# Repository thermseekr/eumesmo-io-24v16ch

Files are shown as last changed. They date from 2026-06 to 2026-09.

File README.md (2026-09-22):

# eumesmo-io-24v16ch
ESP32 based board with 16x optoisolated 24 VDC active high inputs, and 16x open collector 24 VDC outputs.

The outputs are based on the MMBT2222A SMD transistor and are rated for a maximum of 500mA, although it is recommended to limit the current to 350 mA for continous operation. If driving inductive loads like relays, a freewheeling diode or a snubber circuit should be used to limit the switching transients and protect the transistors.

Also included is a 1-Wire interface for external sensors. This interface can be switched to connect either to GPIO16 for use with a bitbang driver like the one available in Tasmota, or to a DS2482S-100 1-Wire master for building more complex networks. Selection is made via SW2, according to the description printed on the PCB. **Attention:** only one dip-switch can be on at any given time.

The board is compatible with the SP7 DIN rail system from [Metaltex](https://www.metaltex.com.br/).

## Hardware Specifications

| Feature | Specification |
| :--- | :--- |
| **Microcontroller** | ESP32-WROOM-32UE-N16 (16MB flash) |
| **Inputs** | 16x 24VDC (optoisolated, active high) |
| **Outputs** | 16x 24VDC (open collector, 350mA cont. / 500mA peak) |
| **Peripherals** | 1-Wire Interface, via GPIO or 1-Wire master |
| **Form Factor** | Metaltex DIN Rail holder Compatible |

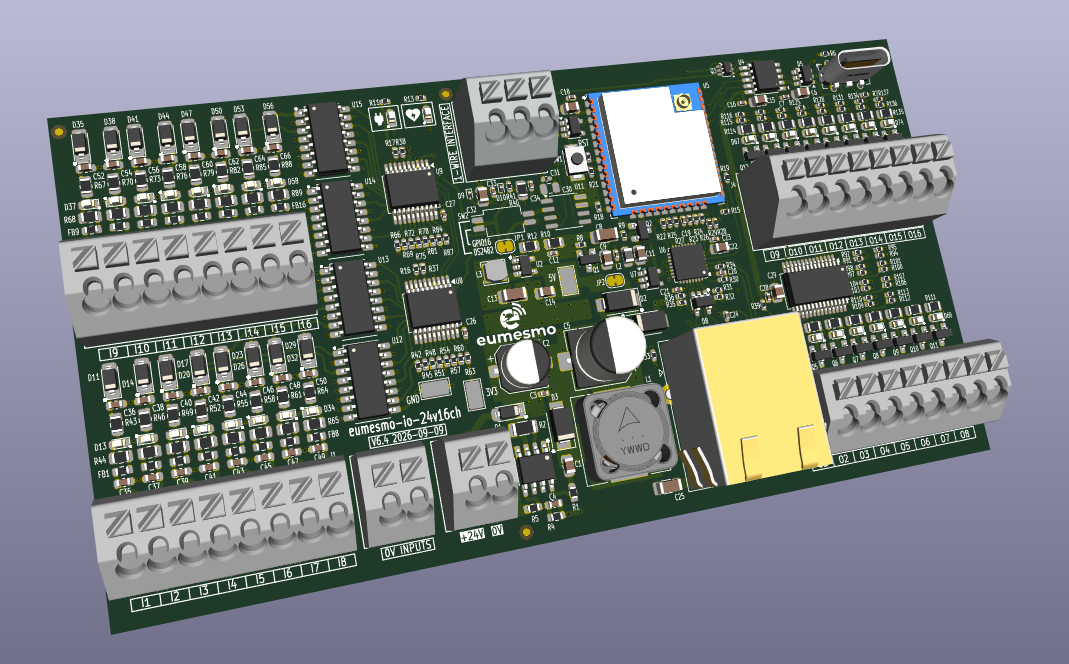
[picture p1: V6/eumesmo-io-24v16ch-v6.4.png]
eumesmo-io-24v16ch V6.4


## VERSION HISTORY

V6.4 - 2026/09/22 - Ethernet connector and terminal blocks moved inwards the PCB to eliminate interference with the PCB holder and make space for the pin descriptions. Tracks between connector and LAN8710A rerouted for improved EMC. LEDs switched from white to orange. Replaced TPS3823-33 for a TPS3820-33 as the LAN8710A reset monitor: the 200ms delay was too much and by the time the chip came up, the ESP32 had already finished booting and had not found it.

V6.3 - 2026/07/02 - Added CPU health LED.

V6.2 - 2026/06/13 - Repository renamed from ESP-24V-16CH to eumesmo-io-24v16ch to align the design with the **eumesmo** line of building automation products.

V6.1 - 2026/06/09 - Added voltage monitors for the reset pins on the ESP32 and LAN8710A, replacing the RC circuits. The idea is to get more reliability on the power up sequence with a more controlled reset scheme and a sharper edge on the reset signal. For the ESP32 a TPS3820-33 was selected, which has a reset delay of 25ms. The LAN8710A received a TPS3823-33 with a 200ms delay. The sequence is: ESP32 gets power and goes out of reset 25ms after power good is detected at the 3V3 rail. After boot GPIO12 will go high enabling the 3V3LAN power rail and feeding power to both LAN8710A and TPS3823-33. Then, 200ms after power good is detected on the 3V3LAN rail, the LAN8710A will go out of reset and the power sequence is completed.

V6.0 - 2026/06/06 - The ESP32 was repositioned to allow for better routing to/from the PHY. Test points and a shunt resistor on the 5V rail were added to be used during tests. Will be remove in later versions. A separate GND plane and connector for optocouplers inputs was included. New ethernet connector, with tab up for easier integration with DIN holders from Metaltex. Connectors were replaced for 3.5mm pitch versions for easier wiring installation in the field. The board had to grow 10mm to accomodate these. SMD capacitor sizes were revised for better performance. Transistor base current for the ouputs was increased from 2,3mA to 5,5mA to ensure better saturation. Now, higher loads can be driven without the risk of putting the transistor in the active region. The MCP23017 expander for the inputs was replaced by 2x MCP23008 to avoid the infamous MCP23017 input bug. Rpacks were replaced for individual resistors for more flexible layout. Talking about layout, it was fully revised with better impedance matching for LAN8710 Tx/Rx signal traces. At last, the loads for 3V3A and 3V3LAN rails were revised.

V5.2 - 2026/02/10 - Pins GPA7 and GPB7 of the input MCP23017 were disabled as recommended by Microchip. Inputs 1 and 2 were assigned to GPIO34 and GPIO35 on the ESP32. The mentioned pins were pulled down to 0V and disabled on the mcp23x.dat template. Templates and GPIO assignment information on the schematics were updated.

V5.1 - Corrected footprint of R7 and repositioned the RESET switch as noted by [@yvkoch](https://github.com/yvkoch). Thanks Yrjö! Improved the 1-Wire bus interface aiming for cable runs up to 50m, still to be tested. Also included the option to connect a GPIO to the 1-Wire bus. ATENTION, SW2 can only have one switch ON at any given time, to connect either the DS2482 or GPIO16 to the 1-Wire bus.

V5.0 - Removed the onboard temperature sensor, too sensitive to be on a PCB and also measure the ambient temperature inside the cabinet. Even with cuts around the sensor, it was better at measuring each transistor's influence on the PCB's temperature than the temperature of the environment. Replaced the analog NTC inputs for a 1-Wire i2c interface. Mixing analog and digital circuits on a PCB requires more testing and developing time than I have available. So, fully digital we go. Decreased the brightness of the LEDs, maybe this time I'll get them right :) Repositioned components and rerouted the whole board following the valuable insights taken from [Phil's Lab](https://github.com/pms67) latest videos about Kicad. Thank you very much, Phil.

V4.1 - Redesigned NTC inputs for using differential mode for better immunity against noise. Also the low pass filters were redesigned, the original ones were pretty much useless for any cable larger that 2 meters.

V4.0 - Redesigned digital inputs for better tolerance to long cable runs in noisy environment. Removed pads for NTC inputs 3 and 4, tied them to GND.

V3.2 - Added 4 NTC inputs using an ADS1115 A/D converter with i2c. Reduced current on the LEDs, brightness was too high. Added series resistor and rerouted clock track for better impedance and ring control. Rerouted TX/RX and SCL/SDA tracks for improved signal quality. Layers reordered so the ground plane is directly below the top layer. Returned ESP32 to 16MB version.

V3.1 - Added AHT20 onboard temperature and humidity sensor for cabinet environment monitoring. Replaced ESP32 16MB for 4MB because no stock at JLCPCB.

V3 - Power LED moved to 5V bus. Individual resistors replaced for rpacks where applicable. Moved from 2 to 4 layers, board reduced 30mm in lenght. USB connector repositioned and replaced for horizontal version.

V2 - All GPIOs moved to MCP23017 expanders. MCP interrupt pins connected to GPIOs on the ESP32. USB connector changed for USB type C.

V1 - Initial version, not released. The first 8 inputs used native ESP32 GPIOs, other inputs and all outputs were wired through MCP GPIO expanders.

## LICENSE

This project is licensed under the [Creative Commons BY-NC 4.0 License](https://creativecommons.org/licenses/by-nc/4.0/).
Commercial use is not permitted without prior written consent. See the [LICENSE.txt](LICENSE.txt) file for details.

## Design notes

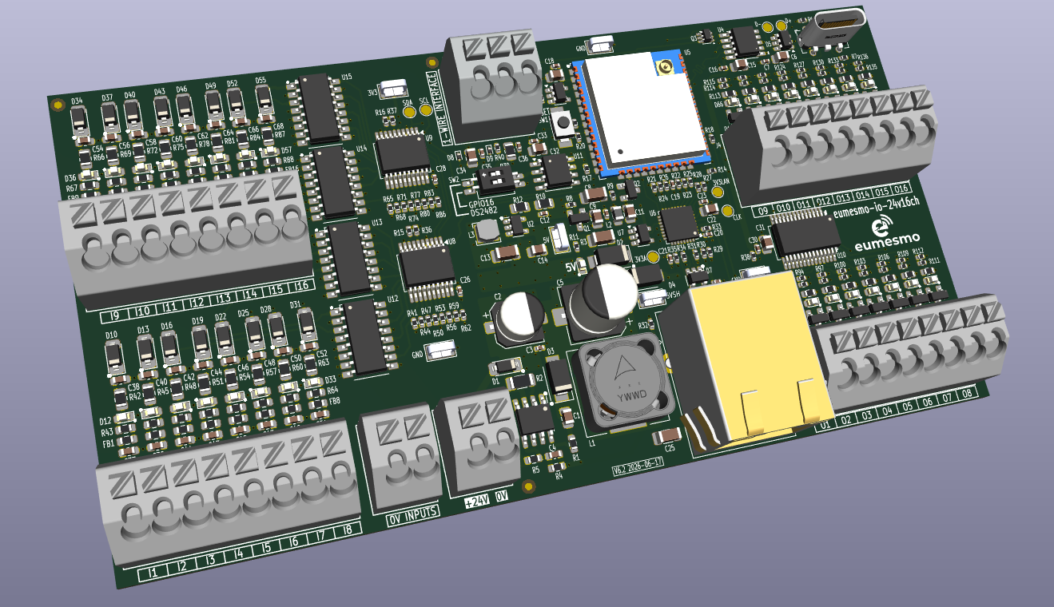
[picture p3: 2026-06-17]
V6/eumesmo-io-24v16ch-v6.2.png

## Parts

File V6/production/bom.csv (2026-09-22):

Designator | Footprint | Quantity | Value | LCSC Part #
C1 | 0805 | 1 | 100nF/100V | C28233
C10, C16, C18, C19, C20, C21, C24, C26, C27, C28, C3, C33, C7 | 0402 | 13 | 100nF/50V | C307331
C11, C14, C15, C17, C29, C32, C9 | 0805 | 7 | 10uF/25V | C15850
C12 | 0402 | 1 | 22pF/50V | C1555
C13, C8 | 1206 | 2 | 22uF/10V | C5672
C2 | CP_Elec_6.3x5.4 | 1 | 47uF/35V | C129415
C22, C6 | 0805 | 2 | 1uF/50V | C28323
C23, C34 | 0402 | 2 | 470pF/50V | C1537
C25 | 1206 | 1 | 1nF/2kV | C9196
C35, C37, C39, C41, C43, C45, C47, C49, C51, C53, C55, C57, C59, C61, C63, C65 | 0603 | 16 | 1nF/50V | C1588
C36, C38, C40, C42, C44, C46, C48, C50, C52, C54, C56, C58, C60, C62, C64, C66 | 0603 | 16 | 33nF/50V | C21117
C4 | 0603 | 1 | 12pF/50V | C38523
C5 | CP_Elec_8x10.5 | 1 | 470uF/16V | C96179
D1 | D_SOD-123 | 1 | SM4007PL | C64898
D10, D9 | D_SOD-923 | 2 | ESD9L5.0 | C82326
D11, D14, D17, D20, D23, D26, D29, D32, D35, D38, D41, D44, D47, D50, D53, D56 | D_SOD-123 | 16 | 9V1/500mW | C19077407
D13, D16, D19, D22, D25, D28, D31, D34, D37, D40, D43, D46, D49, D52, D55, D58, D59, D6, D60, D61, D62, D63, D64, D65, D66, D67, D68, D69, D7, D70, D71, D72, D73, D74 | 0603 | 34 | ORANGE/0603 | C2987557
D2, D4 | D_SMA | 2 | SS34 | C8678
D3 | D_SMA | 1 | SS510 | C65010
D5 | SOT-23-6 | 1 | USBLC6-2SC6 | C7519
D8 | SOT-23-5 | 1 | ESDS314DBV | C1847859
FB1, FB10, FB11, FB12, FB13, FB14, FB15, FB16, FB2, FB3, FB4, FB5, FB6, FB7, FB8, FB9 | 0603 | 16 | 600R/100MHz | C85833
J1, J2, J3, J4 | TerminalBlock_Wago_250-208_1x08_P3.5mm_45Degree | 4 | 250-208 | C2833587
J5, J6 | TerminalBlock_Wago_250-202_1x02_P3.5mm_45Degree | 2 | 250-202 | C2765061
J7 | USB_C_Receptacle_ShouHan_TYPE-C-16PLT-H10.0 | 1 | USB_C_Receptacle_USB2.0 | C3151749
J8 | RJ45_HanRun_HR915340A | 1 | ETHERNET | C6674467
J9 | TerminalBlock_Wago_250-203_1x03_P3.5mm_45Degree | 1 | 250-203 | C2765062
L1 | L_12x12mm_H6mm | 1 | 33uH 2,1A | C3000382
L2 | 0805 | 1 | 2A 600R | C139168
L3 | L_3x3mm_H1.5mm | 1 | 2,2uH 1,5A | C370424
Q1 | SOT-23 | 1 | WPM2015-3/TR | C558305
Q10, Q11, Q12, Q13, Q14, Q15, Q16, Q17, Q18, Q19, Q4, Q5, Q6, Q7, Q8, Q9 | SOT-23-Narrow | 16 | MMBT2222A | C8512
Q2 | SOT-23 | 1 | MMUN2211LT3G | C150229
Q3 | SOT-363_SC-70-6 | 1 | UMH3N | C62892
R1 | 0603 | 1 | 5,1R/100mW | C25197
R10 | 0805 | 1 | 100k/125mW | C149504
R100, R103, R106, R109, R112, R115, R118, R121, R124, R127, R130, R133, R136, R91, R94, R97 | 0402 | 16 | 470R | C25117
R101, R104, R107, R110, R113, R116, R119, R122, R125, R128, R131, R134, R137, R14, R15, R18, R8, R92, R95, R98 | 0402 | 20 | 10k | C60490
R102, R105, R108, R111, R114, R117, R120, R123, R126, R129, R132, R135, R44, R47, R50, R53, R56, R59, R62, R65, R68, R71, R74, R77, R80, R83, R86, R89, R90, R93, R96, R99 | 0805 | 32 | 10k/125mW | C17414
R11, R13 | 0402 | 2 | 680R | C25130
R12 | 0805 | 1 | 22,1k/125mW | C17552
R16, R17, R20, R21, R23, R24, R25, R26, R27, R28, R29, R42, R45, R48, R51, R54, R57, R60, R63, R66, R69, R72, R75, R78, R81, R84, R87 | 0402 | 27 | 2,2k | C25879
R19, R41 | 0402 | 2 | 33R | C25105
R2 | 1206 | 1 | 30mR/333mW | C473665
R22 | 0402 | 1 | 1,5k | C25867
R30 | 0402 | 1 | 12,1k | C281773
R31, R32, R35, R36 | 0402 | 4 | 49,9R | C25120
R33, R34 | 0402 | 2 | 330R | C25104
R37, R38, R39, R9 | 0402 | 4 | 1k | C11702
R4 | 0603 | 1 | 300k/100mW | C23024
R40, R43, R46, R49, R52, R55, R58, R61, R64, R67, R70, R73, R76, R79, R82, R85, R88 | 0805 | 17 | 1,8k/125mW | C17398
R5 | 0603 | 1 | 52,3k/100mW | C23198
R6, R7 | 0402 | 2 | 5,1k | C105872
SW1 | SW_SPST_Xunpu_TS1088AR02016 | 1 | RESET | C720477
U1 | SOIC-8-1EP_3.9x4.9mm_P1.27mm_EP2.41x3.81mm_ThermalVias | 1 | TX4138 | C329267
U10 | SSOP-28_5.3x10.2mm_P0.65mm | 1 | MCP23017 | C506653
U12, U13, U14, U15 | SOP-16_4.4x10.4mm_P1.27mm | 4 | OR-3H7-4 | C2838427
U2 | SOT-23-5_Shorter_Pins | 1 | SY8089A1AAC | C479074
U3, U7 | SOT-23-5 | 2 | TPS3820-33 | C130064
U4 | SSOP-10-1EP_3.9x4.9mm_P1mm_EP2.1x3.3mm | 1 | CH340K | C968586
U5 | ESP32-WROOM-32U | 1 | ESP32-WROOM-32UE-N16 | C701346
U6 | QFN-32-1EP_5x5mm_P0.5mm_EP3.3x3.3mm_ThermalVias | 1 | LAN8710A | C46185
U8, U9 | SSOP-20_5.3x7.2mm_P0.65mm | 2 | MCP23008 | C148011

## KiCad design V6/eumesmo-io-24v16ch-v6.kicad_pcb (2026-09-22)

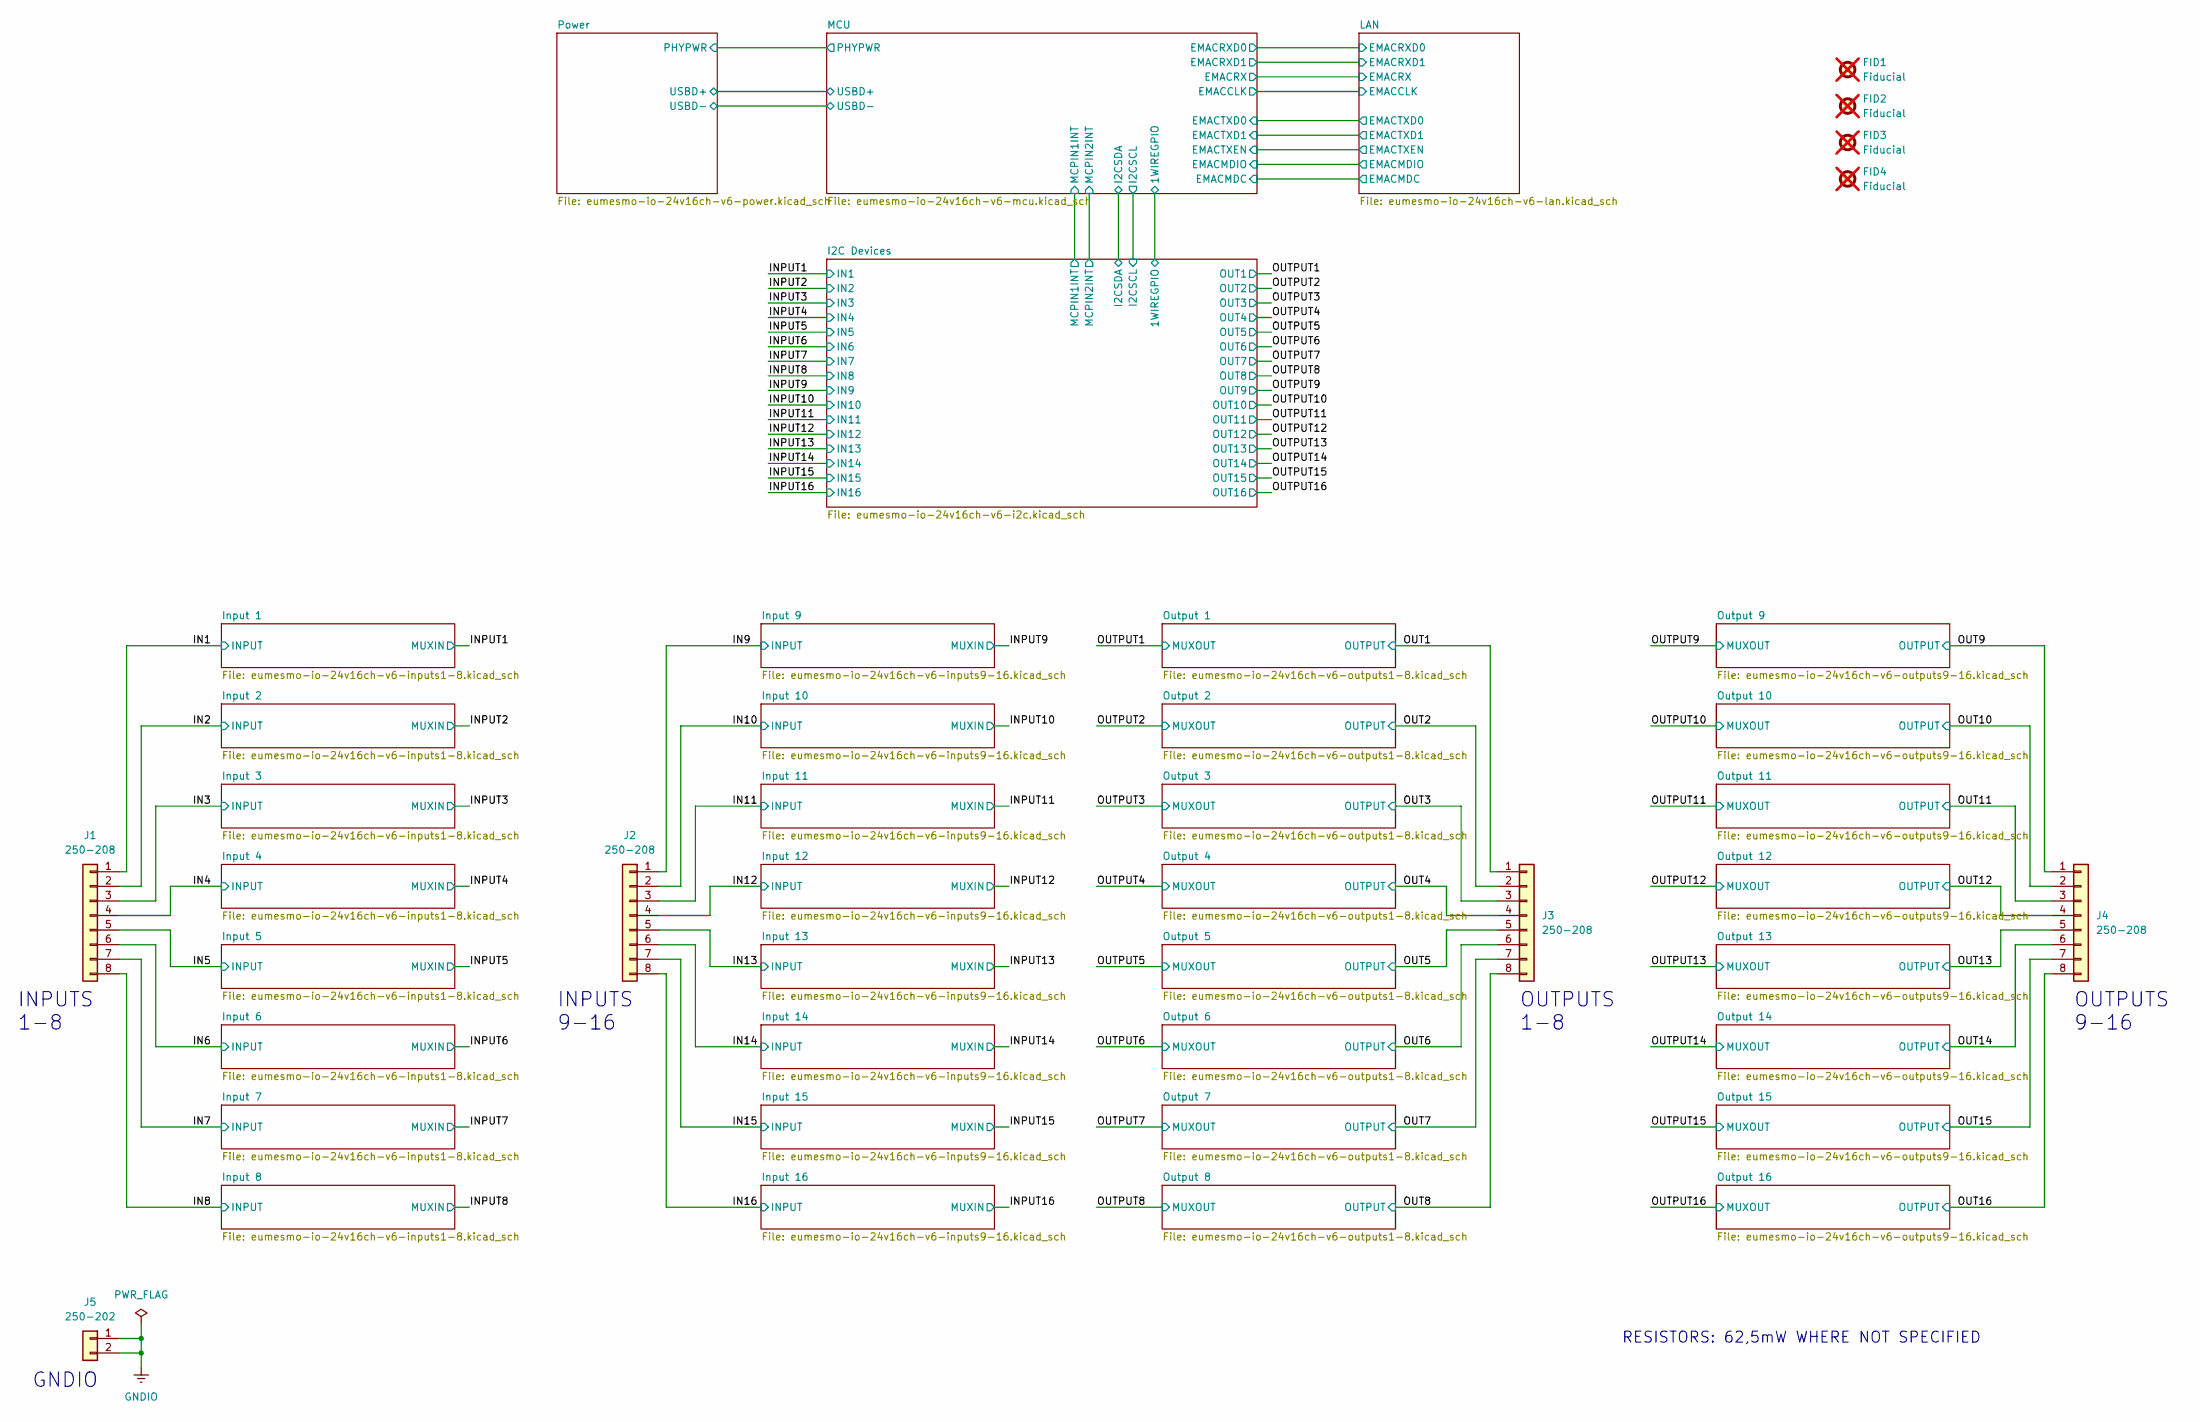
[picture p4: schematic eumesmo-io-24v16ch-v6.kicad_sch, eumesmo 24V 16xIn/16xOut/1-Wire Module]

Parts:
FID1, FID2, FID3, FID4: Fiducial; Fiducial_1mm_Mask2mm; not fitted
J1, J2, J3, J4: 250-208; TerminalBlock_Wago_250-208_1x08_P3.5mm_45Degree; Mfr PN 250-208; LCSC Part # C2833587
J5: 250-202; TerminalBlock_Wago_250-202_1x02_P3.5mm_45Degree; Mfr PN 250-202; LCSC Part # C2765061

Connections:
/IN1: J1.1; also elsewhere on the board
/IN2: J1.2; also elsewhere on the board
/IN3: J1.3; also elsewhere on the board
/IN4: J1.4; also elsewhere on the board
/IN5: J1.5; also elsewhere on the board
/IN6: J1.6; also elsewhere on the board
/IN7: J1.7; also elsewhere on the board
/IN8: J1.8; also elsewhere on the board
/IN9: J2.1; also elsewhere on the board
/IN10: J2.2; also elsewhere on the board
/IN11: J2.3; also elsewhere on the board
/IN12: J2.4; also elsewhere on the board
/IN13: J2.5; also elsewhere on the board
/IN14: J2.6; also elsewhere on the board
/IN15: J2.7; also elsewhere on the board
/IN16: J2.8; also elsewhere on the board
/OUT1: J3.1; also elsewhere on the board
/OUT2: J3.2; also elsewhere on the board
/OUT3: J3.3; also elsewhere on the board
/OUT4: J3.4; also elsewhere on the board
/OUT5: J3.5; also elsewhere on the board
/OUT6: J3.6; also elsewhere on the board
/OUT7: J3.7; also elsewhere on the board
/OUT8: J3.8; also elsewhere on the board
/OUT9: J4.1; also elsewhere on the board
/OUT10: J4.2; also elsewhere on the board
/OUT11: J4.3; also elsewhere on the board
/OUT12: J4.4; also elsewhere on the board
/OUT13: J4.5; also elsewhere on the board
/OUT14: J4.6; also elsewhere on the board
/OUT15: J4.7; also elsewhere on the board
/OUT16: J4.8; also elsewhere on the board
GNDIO: J5.1, J5.2; also elsewhere on the board

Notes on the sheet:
OUTPUTS 1-8
OUTPUTS 9-16
RESISTORS: 62,5mW WHERE NOT SPECIFIED
INPUTS 1-8
GNDIO
INPUTS 9-16

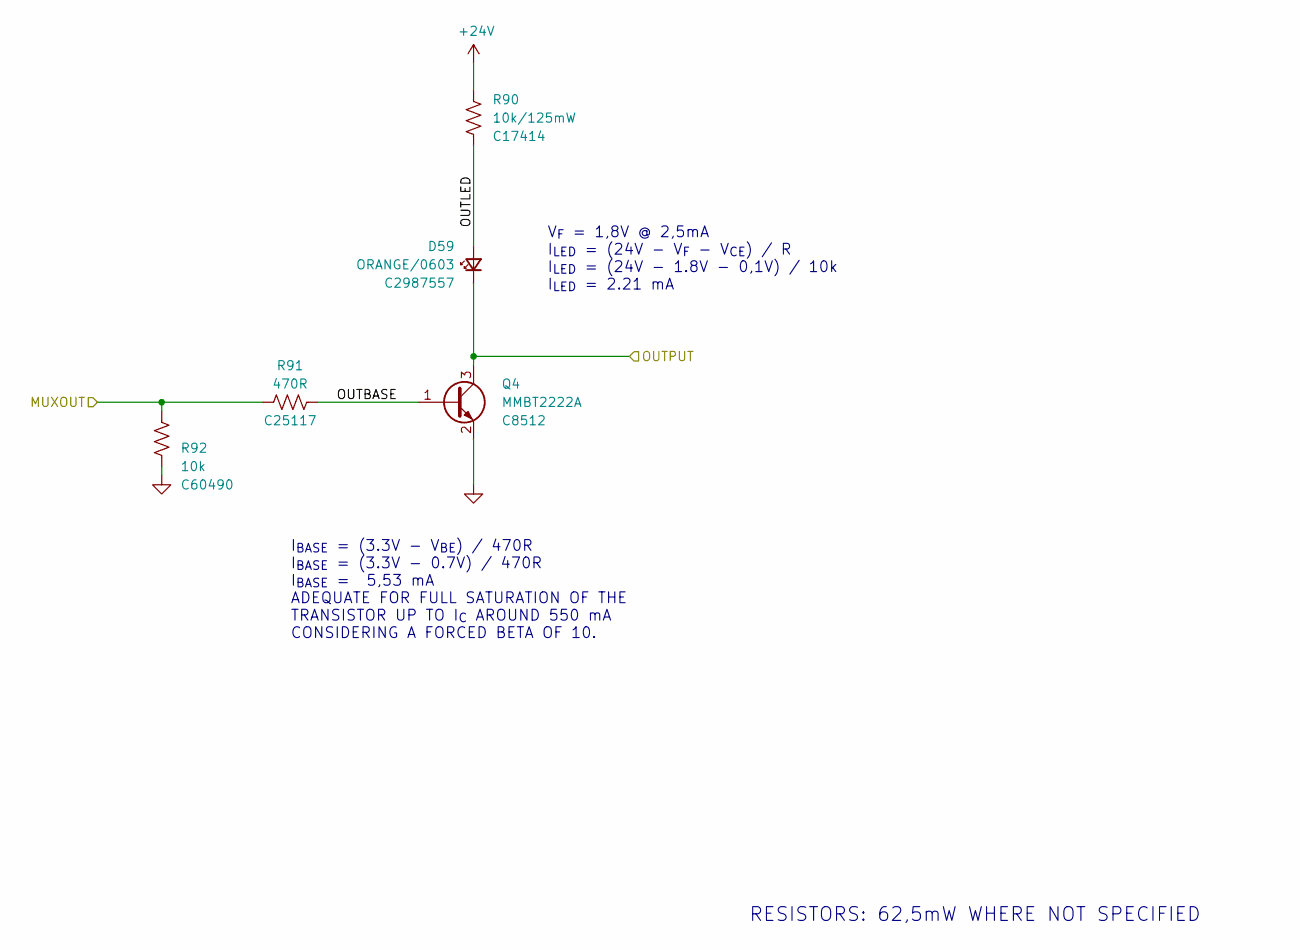
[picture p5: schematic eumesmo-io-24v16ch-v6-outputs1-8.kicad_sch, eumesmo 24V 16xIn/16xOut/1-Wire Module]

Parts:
D59: ORANGE/0603; LED_0603_1608Metric; Mfr PN 19-217/S2C-AL1M2VY/6T; LCSC Part # C2987557
Q4: MMBT2222A; SOT-23-Narrow; Mfr PN MMBT2222A; LCSC Part # C8512
R90: 10k/125mW; R_0805_2012Metric; Mfr PN 0805W8F1002T5E; LCSC Part # C17414
R91: 470R; R_0402_1005Metric; Mfr PN 0402WGF4700TCE; LCSC Part # C25117
R92: 10k; R_0402_1005Metric; Mfr PN RC0402FR-0710KL; LCSC Part # C60490

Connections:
+24V: R90.1; also elsewhere on the board
/OUT1: D59.1 (K), Q4.3 (C); also elsewhere on the board
/OUTPUT1: R91.2, R92.2; also elsewhere on the board
/Output 1/OUTBASE: Q4.1 (B), R91.1
/Output 1/OUTLED: D59.2 (A), R90.2
GND: Q4.2 (E), R92.1; also elsewhere on the board

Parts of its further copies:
D60, D61, D62, D63, D64, D65, D66: ORANGE/0603; LED_0603_1608Metric; Mfr PN 19-217/S2C-AL1M2VY/6T; LCSC Part # C2987557
Q5, Q6, Q7, Q8, Q9, Q10, Q11: MMBT2222A; SOT-23-Narrow; Mfr PN MMBT2222A; LCSC Part # C8512
R93, R96, R99, R102, R105, R108, R111: 10k/125mW; R_0805_2012Metric; Mfr PN 0805W8F1002T5E; LCSC Part # C17414
R94, R97, R100, R103, R106, R109, R112: 470R; R_0402_1005Metric; Mfr PN 0402WGF4700TCE; LCSC Part # C25117
R95, R98, R101, R104, R107, R110, R113: 10k; R_0402_1005Metric; Mfr PN RC0402FR-0710KL; LCSC Part # C60490

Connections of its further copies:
+24V: R93.1, R96.1, R99.1, R102.1, R105.1, R108.1, R111.1; also elsewhere on the board
/OUT2: D60.1 (K), Q5.3 (C); also elsewhere on the board
/OUT3: D61.1 (K), Q6.3 (C); also elsewhere on the board
/OUT4: D62.1 (K), Q7.3 (C); also elsewhere on the board
/OUT5: D63.1 (K), Q8.3 (C); also elsewhere on the board
/OUT6: D64.1 (K), Q9.3 (C); also elsewhere on the board
/OUT7: D65.1 (K), Q10.3 (C); also elsewhere on the board
/OUT8: D66.1 (K), Q11.3 (C); also elsewhere on the board
/OUTPUT2: R94.2, R95.2; also elsewhere on the board
/OUTPUT3: R97.2, R98.2; also elsewhere on the board
/OUTPUT4: R100.2, R101.2; also elsewhere on the board
/OUTPUT5: R103.2, R104.2; also elsewhere on the board
/OUTPUT6: R106.2, R107.2; also elsewhere on the board
/OUTPUT7: R109.2, R110.2; also elsewhere on the board
/OUTPUT8: R112.2, R113.2; also elsewhere on the board
/Output 2/OUTBASE: Q5.1 (B), R94.1
/Output 2/OUTLED: D60.2 (A), R93.2
/Output 3/OUTBASE: Q6.1 (B), R97.1
/Output 3/OUTLED: D61.2 (A), R96.2
/Output 4/OUTBASE: Q7.1 (B), R100.1
/Output 4/OUTLED: D62.2 (A), R99.2
/Output 5/OUTBASE: Q8.1 (B), R103.1
/Output 5/OUTLED: D63.2 (A), R102.2
/Output 6/OUTBASE: Q9.1 (B), R106.1
/Output 6/OUTLED: D64.2 (A), R105.2
/Output 7/OUTBASE: Q10.1 (B), R109.1
/Output 7/OUTLED: D65.2 (A), R108.2
/Output 8/OUTBASE: Q11.1 (B), R112.1
/Output 8/OUTLED: D66.2 (A), R111.2
GND: Q5.2 (E), Q6.2 (E), Q7.2 (E), Q8.2 (E), Q9.2 (E), Q10.2 (E), Q11.2 (E), R95.1, R98.1, R101.1, R104.1, R107.1, R110.1, R113.1; also elsewhere on the board

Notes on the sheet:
V_{F} = 1,8V @ 2,5mA I_{LED} = (24V - V_{F} - V_{CE}) / R I_{LED} = (24V - 1.8V - 0,1V) / 10k I_{LED} = 2.21 mA
RESISTORS: 62,5mW WHERE NOT SPECIFIED
I_{BASE} = (3.3V - V_{BE}) / 470R I_{BASE} = (3.3V - 0.7V) / 470R I_{BASE} = 5,53 mA ADEQUATE FOR FULL SATURATION OF THE TRANSISTOR UP TO I_{C} AROUND 550 mA CONSIDERING A FORCED BETA OF 10.

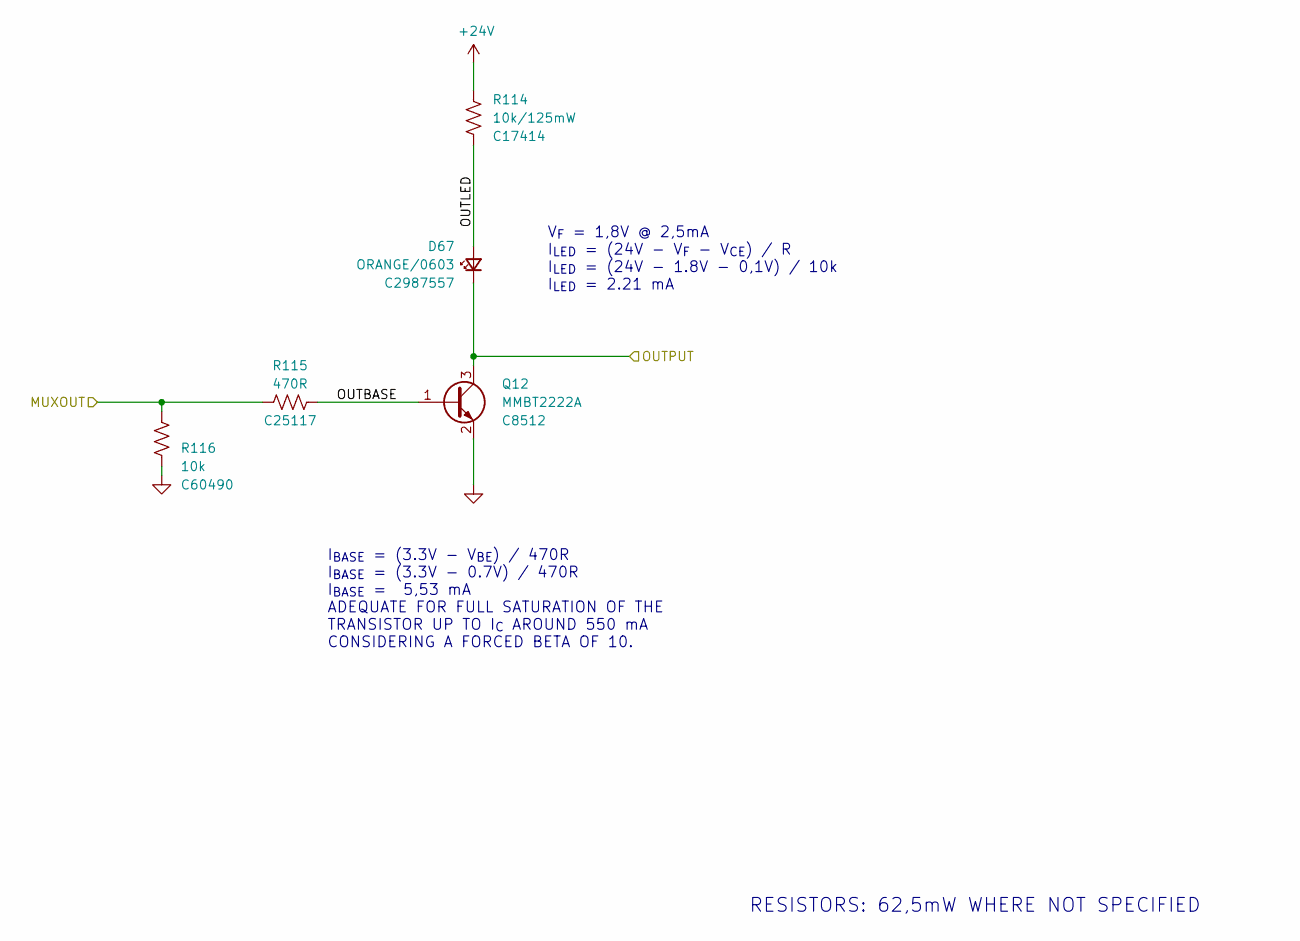
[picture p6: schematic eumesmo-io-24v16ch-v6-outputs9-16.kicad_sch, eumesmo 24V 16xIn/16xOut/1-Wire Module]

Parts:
D67: ORANGE/0603; LED_0603_1608Metric; Mfr PN 19-217/S2C-AL1M2VY/6T; LCSC Part # C2987557
Q12: MMBT2222A; SOT-23-Narrow; Mfr PN MMBT2222A; LCSC Part # C8512
R114: 10k/125mW; R_0805_2012Metric; Mfr PN 0805W8F1002T5E; LCSC Part # C17414
R115: 470R; R_0402_1005Metric; Mfr PN 0402WGF4700TCE; LCSC Part # C25117
R116: 10k; R_0402_1005Metric; Mfr PN RC0402FR-0710KL; LCSC Part # C60490

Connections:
+24V: R114.1; also elsewhere on the board
/OUT9: D67.1 (K), Q12.3 (C); also elsewhere on the board
/OUTPUT9: R115.2, R116.2; also elsewhere on the board
/Output 9/OUTBASE: Q12.1 (B), R115.1
/Output 9/OUTLED: D67.2 (A), R114.2
GND: Q12.2 (E), R116.1; also elsewhere on the board

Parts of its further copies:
D68, D69, D70, D71, D72, D73, D74: ORANGE/0603; LED_0603_1608Metric; Mfr PN 19-217/S2C-AL1M2VY/6T; LCSC Part # C2987557
Q13, Q14, Q15, Q16, Q17, Q18, Q19: MMBT2222A; SOT-23-Narrow; Mfr PN MMBT2222A; LCSC Part # C8512
R117, R120, R123, R126, R129, R132, R135: 10k/125mW; R_0805_2012Metric; Mfr PN 0805W8F1002T5E; LCSC Part # C17414
R118, R121, R124, R127, R130, R133, R136: 470R; R_0402_1005Metric; Mfr PN 0402WGF4700TCE; LCSC Part # C25117
R119, R122, R125, R128, R131, R134, R137: 10k; R_0402_1005Metric; Mfr PN RC0402FR-0710KL; LCSC Part # C60490

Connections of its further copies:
+24V: R117.1, R120.1, R123.1, R126.1, R129.1, R132.1, R135.1; also elsewhere on the board
/OUT10: D68.1 (K), Q13.3 (C); also elsewhere on the board
/OUT11: D69.1 (K), Q14.3 (C); also elsewhere on the board
/OUT12: D70.1 (K), Q15.3 (C); also elsewhere on the board
/OUT13: D71.1 (K), Q16.3 (C); also elsewhere on the board
/OUT14: D72.1 (K), Q17.3 (C); also elsewhere on the board
/OUT15: D73.1 (K), Q18.3 (C); also elsewhere on the board
/OUT16: D74.1 (K), Q19.3 (C); also elsewhere on the board
/OUTPUT10: R118.2, R119.2; also elsewhere on the board
/OUTPUT11: R121.2, R122.2; also elsewhere on the board
/OUTPUT12: R124.2, R125.2; also elsewhere on the board
/OUTPUT13: R127.2, R128.2; also elsewhere on the board
/OUTPUT14: R130.2, R131.2; also elsewhere on the board
/OUTPUT15: R133.2, R134.2; also elsewhere on the board
/OUTPUT16: R136.2, R137.2; also elsewhere on the board
/Output 10/OUTBASE: Q13.1 (B), R118.1
/Output 10/OUTLED: D68.2 (A), R117.2
/Output 11/OUTBASE: Q14.1 (B), R121.1
/Output 11/OUTLED: D69.2 (A), R120.2
/Output 12/OUTBASE: Q15.1 (B), R124.1
/Output 12/OUTLED: D70.2 (A), R123.2
/Output 13/OUTBASE: Q16.1 (B), R127.1
/Output 13/OUTLED: D71.2 (A), R126.2
/Output 14/OUTBASE: Q17.1 (B), R130.1
/Output 14/OUTLED: D72.2 (A), R129.2
/Output 15/OUTBASE: Q18.1 (B), R133.1
/Output 15/OUTLED: D73.2 (A), R132.2
/Output 16/OUTBASE: Q19.1 (B), R136.1
/Output 16/OUTLED: D74.2 (A), R135.2
GND: Q13.2 (E), Q14.2 (E), Q15.2 (E), Q16.2 (E), Q17.2 (E), Q18.2 (E), Q19.2 (E), R119.1, R122.1, R125.1, R128.1, R131.1, R134.1, R137.1; also elsewhere on the board

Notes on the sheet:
RESISTORS: 62,5mW WHERE NOT SPECIFIED
I_{BASE} = (3.3V - V_{BE}) / 470R I_{BASE} = (3.3V - 0.7V) / 470R I_{BASE} = 5,53 mA ADEQUATE FOR FULL SATURATION OF THE TRANSISTOR UP TO I_{C} AROUND 550 mA CONSIDERING A FORCED BETA OF 10.
V_{F} = 1,8V @ 2,5mA I_{LED} = (24V - V_{F} - V_{CE}) / R I_{LED} = (24V - 1.8V - 0,1V) / 10k I_{LED} = 2.21 mA

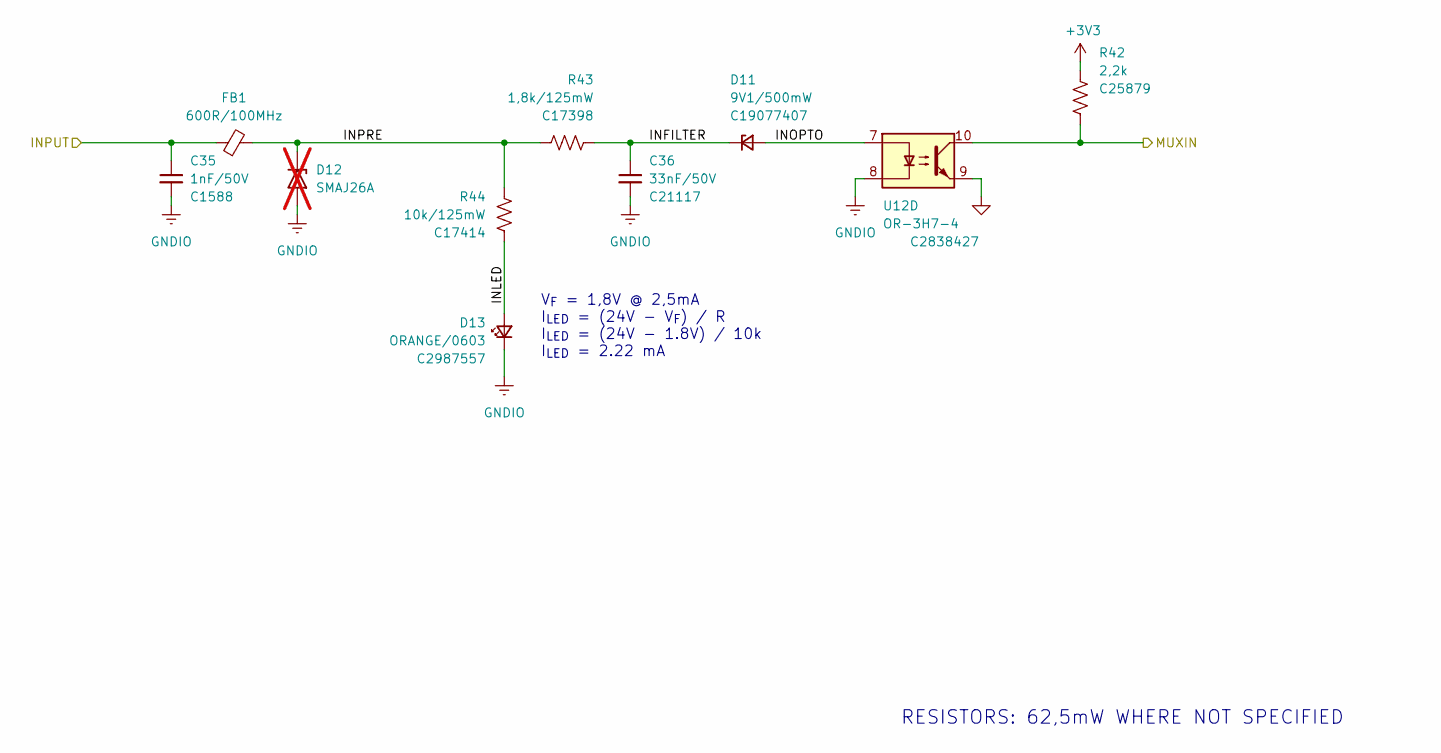
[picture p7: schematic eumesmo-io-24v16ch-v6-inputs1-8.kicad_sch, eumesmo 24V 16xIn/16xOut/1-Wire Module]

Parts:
C35: 1nF/50V; C_0603_1608Metric; Mfr PN CL10B102KB8NNNC; LCSC Part # C1588
C36: 33nF/50V; C_0603_1608Metric; Mfr PN CL10B333KB8NNNC; LCSC Part # C21117
D11: 9V1/500mW; D_SOD-123; Mfr PN BZT52C9V1; LCSC Part # C19077407
D12: SMAJ26A; D_SMA; Mfr PN SMAJ26A; LCSC Part # C19077543; not fitted
D13: ORANGE/0603; LED_0603_1608Metric; Mfr PN 19-217/S2C-AL1M2VY/6T; LCSC Part # C2987557
FB1: 600R/100MHz; R_0603_1608Metric; Mfr PN BLM18KG601SN1D; LCSC Part # C85833
R42: 2,2k; R_0402_1005Metric; Mfr PN 0402WGF2201TCE; LCSC Part # C25879
R43: 1,8k/125mW; R_0805_2012Metric; Mfr PN 0805W8F1801T5E; LCSC Part # C17398
R44: 10k/125mW; R_0805_2012Metric; Mfr PN 0805W8F1002T5E; LCSC Part # C17414
U12: OR-3H7-4; SOP-16_4.4x10.4mm_P1.27mm; Mfr PN OR-3H7-4GB-TA1-G; LCSC Part # C2838427

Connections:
+3V3: R42.1; also elsewhere on the board
/IN1: C35.1, FB1.1; also elsewhere on the board
/INPUT1: R42.2, U12.10; also elsewhere on the board
/INPUT2: U12.12; also elsewhere on the board
/INPUT3: U12.14; also elsewhere on the board
/INPUT4: U12.16; also elsewhere on the board
/Input 1/INFILTER: C36.1, D11.1 (K), R43.1
/Input 1/INLED: D13.2 (A), R44.2
/Input 1/INOPTO: D11.2 (A), U12.7
/Input 1/INPRE: FB1.2, R43.2, R44.1
/Input 2/INOPTO: U12.5; also elsewhere on the board
/Input 3/INOPTO: U12.3; also elsewhere on the board
/Input 4/INOPTO: U12.1; also elsewhere on the board
GND: U12.9, U12.11, U12.13, U12.15; also elsewhere on the board
GNDIO: C35.2, C36.2, D12.2 (A2), D13.1 (K), U12.2, U12.4, U12.6, U12.8; also elsewhere on the board

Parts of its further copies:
C37, C39, C41, C43, C45, C47, C49: 1nF/50V; C_0603_1608Metric; Mfr PN CL10B102KB8NNNC; LCSC Part # C1588
C38, C40, C42, C44, C46, C48, C50: 33nF/50V; C_0603_1608Metric; Mfr PN CL10B333KB8NNNC; LCSC Part # C21117
D14, D17, D20, D23, D26, D29, D32: 9V1/500mW; D_SOD-123; Mfr PN BZT52C9V1; LCSC Part # C19077407
D16, D19, D22, D25, D28, D31, D34: ORANGE/0603; LED_0603_1608Metric; Mfr PN 19-217/S2C-AL1M2VY/6T; LCSC Part # C2987557
FB2, FB3, FB4, FB5, FB6, FB7, FB8: 600R/100MHz; R_0603_1608Metric; Mfr PN BLM18KG601SN1D; LCSC Part # C85833
R45, R48, R51, R54, R57, R60, R63: 2,2k; R_0402_1005Metric; Mfr PN 0402WGF2201TCE; LCSC Part # C25879
R46, R49, R52, R55, R58, R61, R64: 1,8k/125mW; R_0805_2012Metric; Mfr PN 0805W8F1801T5E; LCSC Part # C17398
R47, R50, R53, R56, R59, R62, R65: 10k/125mW; R_0805_2012Metric; Mfr PN 0805W8F1002T5E; LCSC Part # C17414
U13: OR-3H7-4; SOP-16_4.4x10.4mm_P1.27mm; Mfr PN OR-3H7-4GB-TA1-G; LCSC Part # C2838427

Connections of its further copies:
+3V3: R45.1, R48.1, R51.1, R54.1, R57.1, R60.1, R63.1; also elsewhere on the board
/IN2: C37.1, FB2.1; also elsewhere on the board
/IN3: C39.1, FB3.1; also elsewhere on the board
/IN4: C41.1, FB4.1; also elsewhere on the board
/IN5: C43.1, FB5.1; also elsewhere on the board
/IN6: C45.1, FB6.1; also elsewhere on the board
/IN7: C47.1, FB7.1; also elsewhere on the board
/IN8: C49.1, FB8.1; also elsewhere on the board
/INPUT2: R45.2; also elsewhere on the board
/INPUT3: R48.2; also elsewhere on the board
/INPUT4: R51.2; also elsewhere on the board
/INPUT5: R54.2, U13.10; also elsewhere on the board
/INPUT6: R57.2, U13.12; also elsewhere on the board
/INPUT7: R60.2, U13.14; also elsewhere on the board
/INPUT8: R63.2, U13.16; also elsewhere on the board
/Input 2/INFILTER: C38.1, D14.1 (K), R46.1
/Input 2/INLED: D16.2 (A), R47.2
/Input 2/INOPTO: D14.2 (A); also elsewhere on the board
/Input 2/INPRE: FB2.2, R46.2, R47.1
/Input 3/INFILTER: C40.1, D17.1 (K), R49.1
/Input 3/INLED: D19.2 (A), R50.2
/Input 3/INOPTO: D17.2 (A); also elsewhere on the board
/Input 3/INPRE: FB3.2, R49.2, R50.1
/Input 4/INFILTER: C42.1, D20.1 (K), R52.1
/Input 4/INLED: D22.2 (A), R53.2
/Input 4/INOPTO: D20.2 (A); also elsewhere on the board
/Input 4/INPRE: FB4.2, R52.2, R53.1
/Input 5/INFILTER: C44.1, D23.1 (K), R55.1
/Input 5/INLED: D25.2 (A), R56.2
/Input 5/INOPTO: D23.2 (A), U13.7
/Input 5/INPRE: FB5.2, R55.2, R56.1
/Input 6/INFILTER: C46.1, D26.1 (K), R58.1
/Input 6/INLED: D28.2 (A), R59.2
/Input 6/INOPTO: D26.2 (A), U13.5
/Input 6/INPRE: FB6.2, R58.2, R59.1
/Input 7/INFILTER: C48.1, D29.1 (K), R61.1
/Input 7/INLED: D31.2 (A), R62.2
/Input 7/INOPTO: D29.2 (A), U13.3
/Input 7/INPRE: FB7.2, R61.2, R62.1
/Input 8/INFILTER: C50.1, D32.1 (K), R64.1
/Input 8/INLED: D34.2 (A), R65.2
/Input 8/INOPTO: D32.2 (A), U13.1
/Input 8/INPRE: FB8.2, R64.2, R65.1
GND: U13.9, U13.11, U13.13, U13.15; also elsewhere on the board
GNDIO: C37.2, C38.2, C39.2, C40.2, C41.2, C42.2, C43.2, C44.2, C45.2, C46.2, C47.2, C48.2, C49.2, C50.2, D16.1 (K), D19.1 (K), D22.1 (K), D25.1 (K), D28.1 (K), D31.1 (K), D34.1 (K), U13.2, U13.4, U13.6, U13.8; also elsewhere on the board

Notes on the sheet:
V_{F} = 1,8V @ 2,5mA I_{LED} = (24V - V_{F}) / R I_{LED} = (24V - 1.8V) / 10k I_{LED} = 2.22 mA
RESISTORS: 62,5mW WHERE NOT SPECIFIED

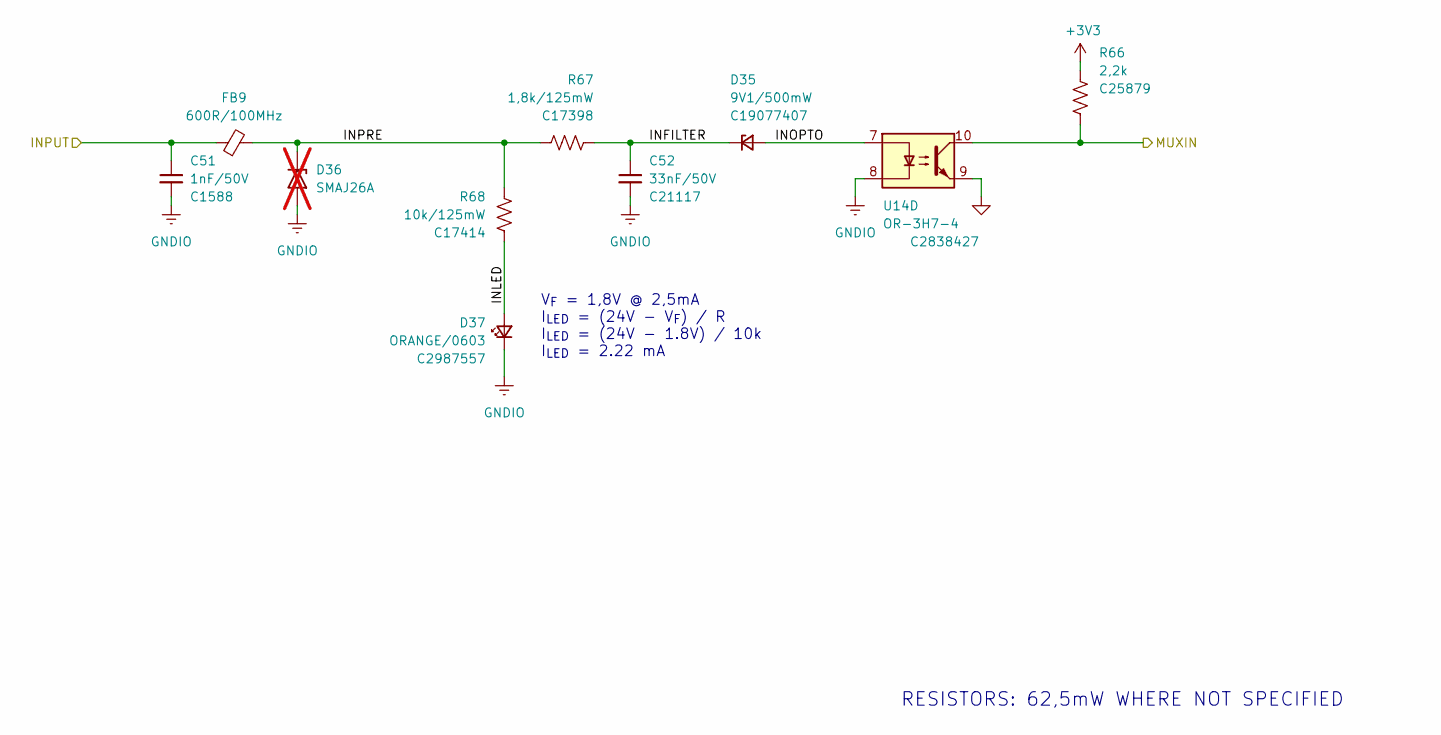
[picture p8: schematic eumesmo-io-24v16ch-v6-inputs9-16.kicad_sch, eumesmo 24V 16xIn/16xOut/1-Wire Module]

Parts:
C51: 1nF/50V; C_0603_1608Metric; Mfr PN CL10B102KB8NNNC; LCSC Part # C1588
C52: 33nF/50V; C_0603_1608Metric; Mfr PN CL10B333KB8NNNC; LCSC Part # C21117
D35: 9V1/500mW; D_SOD-123; Mfr PN BZT52C9V1; LCSC Part # C19077407
D36: SMAJ26A; D_SMA; Mfr PN SMAJ26A; LCSC Part # C19077543; not fitted
D37: ORANGE/0603; LED_0603_1608Metric; Mfr PN 19-217/S2C-AL1M2VY/6T; LCSC Part # C2987557
FB9: 600R/100MHz; R_0603_1608Metric; Mfr PN BLM18KG601SN1D; LCSC Part # C85833
R66: 2,2k; R_0402_1005Metric; Mfr PN 0402WGF2201TCE; LCSC Part # C25879
R67: 1,8k/125mW; R_0805_2012Metric; Mfr PN 0805W8F1801T5E; LCSC Part # C17398
R68: 10k/125mW; R_0805_2012Metric; Mfr PN 0805W8F1002T5E; LCSC Part # C17414
U14: OR-3H7-4; SOP-16_4.4x10.4mm_P1.27mm; Mfr PN OR-3H7-4GB-TA1-G; LCSC Part # C2838427

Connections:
+3V3: R66.1; also elsewhere on the board
/IN9: C51.1, FB9.1; also elsewhere on the board
/INPUT9: R66.2, U14.10; also elsewhere on the board
/INPUT10: U14.12; also elsewhere on the board
/INPUT11: U14.14; also elsewhere on the board
/INPUT12: U14.16; also elsewhere on the board
/Input 9/INFILTER: C52.1, D35.1 (K), R67.1
/Input 9/INLED: D37.2 (A), R68.2
/Input 9/INOPTO: D35.2 (A), U14.7
/Input 9/INPRE: FB9.2, R67.2, R68.1
/Input 10/INOPTO: U14.5; also elsewhere on the board
/Input 11/INOPTO: U14.3; also elsewhere on the board
/Input 12/INOPTO: U14.1; also elsewhere on the board
GND: U14.9, U14.11, U14.13, U14.15; also elsewhere on the board
GNDIO: C51.2, C52.2, D36.2 (A2), D37.1 (K), U14.2, U14.4, U14.6, U14.8; also elsewhere on the board

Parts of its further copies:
C53, C55, C57, C59, C61, C63, C65: 1nF/50V; C_0603_1608Metric; Mfr PN CL10B102KB8NNNC; LCSC Part # C1588
C54, C56, C58, C60, C62, C64, C66: 33nF/50V; C_0603_1608Metric; Mfr PN CL10B333KB8NNNC; LCSC Part # C21117
D38, D41, D44, D47, D50, D53, D56: 9V1/500mW; D_SOD-123; Mfr PN BZT52C9V1; LCSC Part # C19077407
D40, D43, D46, D49, D52, D55, D58: ORANGE/0603; LED_0603_1608Metric; Mfr PN 19-217/S2C-AL1M2VY/6T; LCSC Part # C2987557
FB10, FB11, FB12, FB13, FB14, FB15, FB16: 600R/100MHz; R_0603_1608Metric; Mfr PN BLM18KG601SN1D; LCSC Part # C85833
R69, R72, R75, R78, R81, R84, R87: 2,2k; R_0402_1005Metric; Mfr PN 0402WGF2201TCE; LCSC Part # C25879
R70, R73, R76, R79, R82, R85, R88: 1,8k/125mW; R_0805_2012Metric; Mfr PN 0805W8F1801T5E; LCSC Part # C17398
R71, R74, R77, R80, R83, R86, R89: 10k/125mW; R_0805_2012Metric; Mfr PN 0805W8F1002T5E; LCSC Part # C17414
U15: OR-3H7-4; SOP-16_4.4x10.4mm_P1.27mm; Mfr PN OR-3H7-4GB-TA1-G; LCSC Part # C2838427

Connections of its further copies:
+3V3: R69.1, R72.1, R75.1, R78.1, R81.1, R84.1, R87.1; also elsewhere on the board
/IN10: C53.1, FB10.1; also elsewhere on the board
/IN11: C55.1, FB11.1; also elsewhere on the board
/IN12: C57.1, FB12.1; also elsewhere on the board
/IN13: C59.1, FB13.1; also elsewhere on the board
/IN14: C61.1, FB14.1; also elsewhere on the board
/IN15: C63.1, FB15.1; also elsewhere on the board
/IN16: C65.1, FB16.1; also elsewhere on the board
/INPUT10: R69.2; also elsewhere on the board
/INPUT11: R72.2; also elsewhere on the board
/INPUT12: R75.2; also elsewhere on the board
/INPUT13: R78.2, U15.10; also elsewhere on the board
/INPUT14: R81.2, U15.12; also elsewhere on the board
/INPUT15: R84.2, U15.14; also elsewhere on the board
/INPUT16: R87.2, U15.16; also elsewhere on the board
/Input 10/INFILTER: C54.1, D38.1 (K), R70.1
/Input 10/INLED: D40.2 (A), R71.2
/Input 10/INOPTO: D38.2 (A); also elsewhere on the board
/Input 10/INPRE: FB10.2, R70.2, R71.1
/Input 11/INFILTER: C56.1, D41.1 (K), R73.1
/Input 11/INLED: D43.2 (A), R74.2
/Input 11/INOPTO: D41.2 (A); also elsewhere on the board
/Input 11/INPRE: FB11.2, R73.2, R74.1
/Input 12/INFILTER: C58.1, D44.1 (K), R76.1
/Input 12/INLED: D46.2 (A), R77.2
/Input 12/INOPTO: D44.2 (A); also elsewhere on the board
/Input 12/INPRE: FB12.2, R76.2, R77.1
/Input 13/INFILTER: C60.1, D47.1 (K), R79.1
/Input 13/INLED: D49.2 (A), R80.2
/Input 13/INOPTO: D47.2 (A), U15.7
/Input 13/INPRE: FB13.2, R79.2, R80.1
/Input 14/INFILTER: C62.1, D50.1 (K), R82.1
/Input 14/INLED: D52.2 (A), R83.2
/Input 14/INOPTO: D50.2 (A), U15.5
/Input 14/INPRE: FB14.2, R82.2, R83.1
/Input 15/INFILTER: C64.1, D53.1 (K), R85.1
/Input 15/INLED: D55.2 (A), R86.2
/Input 15/INOPTO: D53.2 (A), U15.3
/Input 15/INPRE: FB15.2, R85.2, R86.1
/Input 16/INFILTER: C66.1, D56.1 (K), R88.1
/Input 16/INLED: D58.2 (A), R89.2
/Input 16/INOPTO: D56.2 (A), U15.1
/Input 16/INPRE: FB16.2, R88.2, R89.1
GND: U15.9, U15.11, U15.13, U15.15; also elsewhere on the board
GNDIO: C53.2, C54.2, C55.2, C56.2, C57.2, C58.2, C59.2, C60.2, C61.2, C62.2, C63.2, C64.2, C65.2, C66.2, D40.1 (K), D43.1 (K), D46.1 (K), D49.1 (K), D52.1 (K), D55.1 (K), D58.1 (K), U15.2, U15.4, U15.6, U15.8; also elsewhere on the board

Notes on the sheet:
V_{F} = 1,8V @ 2,5mA I_{LED} = (24V - V_{F}) / R I_{LED} = (24V - 1.8V) / 10k I_{LED} = 2.22 mA
RESISTORS: 62,5mW WHERE NOT SPECIFIED

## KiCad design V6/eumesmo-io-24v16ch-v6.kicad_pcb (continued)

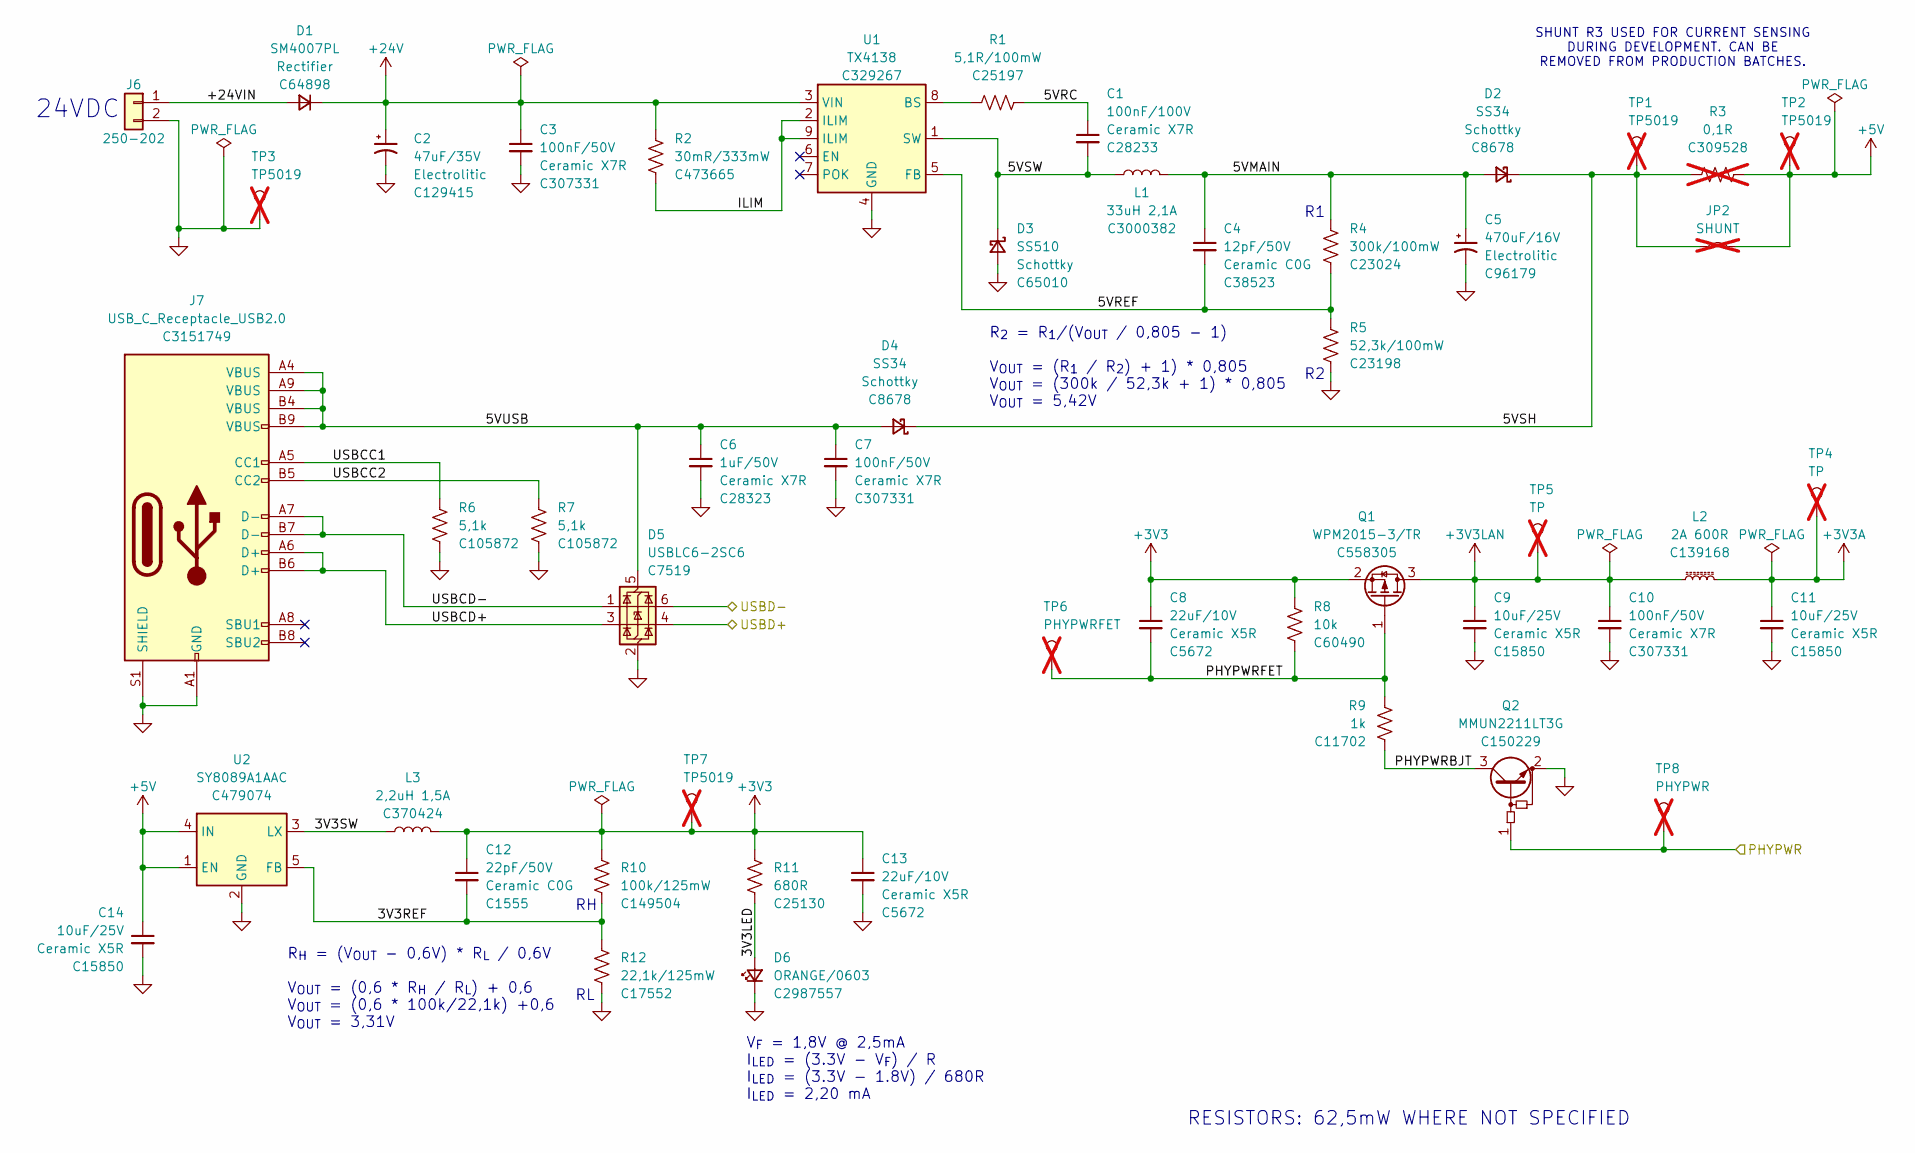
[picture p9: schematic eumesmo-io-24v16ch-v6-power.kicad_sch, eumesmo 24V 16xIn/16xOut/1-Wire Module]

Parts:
C1: 100nF/100V; C_0805_2012Metric; Mfr PN CL21B104KCFNNNE; LCSC Part # C28233
C2: 47uF/35V; CP_Elec_6.3x5.4; Mfr PN CK1V470M-CRE54; LCSC Part # C129415
C3, C7, C10: 100nF/50V; C_0402_1005Metric; Mfr PN CL05B104KB54PNC; LCSC Part # C307331
C4: 12pF/50V; C_0603_1608Metric; Mfr PN CL10C120JB8NNNC; LCSC Part # C38523
C5: 470uF/16V; CP_Elec_8x10.5; Mfr PN CS1C471M-CRF10; LCSC Part # C96179
C6: 1uF/50V; C_0805_2012Metric; Mfr PN CL21B105KBFNNNE; LCSC Part # C28323
C8, C13: 22uF/10V; C_1206_3216Metric; Mfr PN CL31A226KPHNNNE; LCSC Part # C5672
C9, C11, C14: 10uF/25V; C_0805_2012Metric; Mfr PN CL21A106KAYNNNE; LCSC Part # C15850
C12: 22pF/50V; C_0402_1005Metric; Mfr PN 0402CG220J500NT; LCSC Part # C1555
D1: SM4007PL; D_SOD-123; Mfr PN SM4007PL; LCSC Part # C64898
D2, D4: SS34; D_SMA; Mfr PN SS34; LCSC Part # C8678
D3: SS510; D_SMA; Mfr PN SS510; LCSC Part # C65010
D5: USBLC6-2SC6; SOT-23-6; Mfr PN USBLC6-2SC6; LCSC Part # C7519
D6: ORANGE/0603; LED_0603_1608Metric; Mfr PN 19-217/S2C-AL1M2VY/6T; LCSC Part # C2987557
J6: 250-202; TerminalBlock_Wago_250-202_1x02_P3.5mm_45Degree; Mfr PN 250-202; LCSC Part # C2765061
J7: USB_C_Receptacle_USB2.0; USB_C_Receptacle_ShouHan_TYPE-C-16PLT-H10.0; Mfr PN TYPE-C 16PLT-H10.0; LCSC Part # C3151749
JP2: SHUNT; SolderJumper-2_P1.3mm_Bridged_RoundedPad1.0x1.5mm; not fitted
L1: 33uH 2,1A; L_12x12mm_H6mm; Mfr PN SMDRI125-330MT; LCSC Part # C3000382
L2: 2A 600R; L_0805_2012Metric; Mfr PN CBM201209U601T; LCSC Part # C139168
L3: 2,2uH 1,5A; L_3x3mm_H1.5mm; Mfr PN SPH3015H2R2MT; LCSC Part # C370424
Q1: WPM2015-3/TR; SOT-23; Mfr PN WPM2015-3/TR; LCSC Part # C558305
Q2: MMUN2211LT3G; SOT-23; Mfr PN MMUN2211LT3G; LCSC Part # C150229
R1: 5,1R/100mW; R_0603_1608Metric; Mfr PN 0603WAF510KT5E; LCSC Part # C25197
R2: 30mR/333mW; R_1206_3216Metric; Mfr PN 1206W3F300MT5E; LCSC Part # C473665
R3: 0,1R; C_1206_3216Metric; Mfr PN PE1206FRF470R1L; LCSC Part # C309528; not fitted
R4: 300k/100mW; R_0603_1608Metric; Mfr PN 0603WAF3003T5E; LCSC Part # C23024
R5: 52,3k/100mW; R_0603_1608Metric; Mfr PN 0603WAF5232T5E; LCSC Part # C23198
R6, R7: 5,1k; R_0402_1005Metric; Mfr PN RC0402FR-075K1L; LCSC Part # C105872
R8: 10k; R_0402_1005Metric; Mfr PN RC0402FR-0710KL; LCSC Part # C60490
R9: 1k; R_0402_1005Metric; Mfr PN 0402WGF1001TCE; LCSC Part # C11702
R10: 100k/125mW; R_0805_2012Metric; Mfr PN 0805W8F1003T5E; LCSC Part # C149504
R11: 680R; R_0402_1005Metric; Mfr PN 0402WGF6800TCE; LCSC Part # C25130
R12: 22,1k/125mW; R_0805_2012Metric; Mfr PN 0805W8F2212T5E; LCSC Part # C17552
TP1, TP2, TP3, TP7: TP5019; TestPoint_Keystone_5019_Miniature; Mfr PN 5019; LCSC Part # C238131; not fitted
TP4, TP5: TP; TestPoint_Pad_D1.5mm; not fitted
TP6: PHYPWRFET; TestPoint_Pad_D1.5mm; not fitted
TP8: PHYPWR; TestPoint_Pad_D1.5mm; not fitted
U1: TX4138; SOIC-8-1EP_3.9x4.9mm_P1.27mm_EP2.41x3.81mm_ThermalVias; Mfr PN TX4138; LCSC Part # C329267
U2: SY8089A1AAC; SOT-23-5_Shorter_Pins; Mfr PN SY8089A1AAC; LCSC Part # C479074

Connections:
+3V3: C8.1, C12.1, C13.1, L3.2, Q1.2 (S), R8.1, R10.1, R11.1, TP7.1 (1_1); also elsewhere on the board
+3V3A: C11.1, L2.2, TP4.1; also elsewhere on the board
+3V3LAN: C9.1, C10.1, L2.1, Q1.3 (D), TP5.1; also elsewhere on the board
+5V: C14.1, JP2.2 (B), R3.1, TP2.1 (1_1), U2.1 (EN), U2.4 (IN); also elsewhere on the board
+24V: C2.1, C3.1, D1.1 (K), R2.1, U1.3 (VIN); also elsewhere on the board
/MCU/PHYPWR: Q2.1 (B), TP8.1; also elsewhere on the board
/MCU/USBD+: D5.4 (I/O2); also elsewhere on the board
/MCU/USBD-: D5.6 (I/O1); also elsewhere on the board
/Power/3V3LED: D6.2 (A), R11.2
/Power/3V3REF: C12.2, R10.2, R12.1, U2.5 (FB)
/Power/3V3SW: L3.1, U2.3 (LX)
/Power/5VMAIN: C4.1, C5.1, D2.2 (A), L1.2, R4.1
/Power/5VRC: C1.1, R1.1
/Power/5VREF: C4.2, R4.2, R5.1, U1.5 (FB)
/Power/5VSH: D2.1 (K), D4.1 (K), JP2.1 (A), R3.2, TP1.1
/Power/5VSW: C1.2, D3.1 (K), L1.1, U1.1 (SW)
/Power/5VUSB: C6.1, C7.1, D4.2 (A), D5.5 (VBUS), J7.A4 (VBUS), J7.A9 (VBUS), J7.B4 (VBUS), J7.B9 (VBUS)
/Power/+24VIN: D1.2 (A), J6.1
/Power/ILIM: R2.2, U1.2 (ILIM), U1.9 (ILIM)
/Power/PHYPWRBJT: Q2.3 (C), R9.1
/Power/PHYPWRFET: C8.2, Q1.1 (G), R8.2, R9.2, TP6.1
/Power/USBCC1: J7.A5 (CC1), R6.1
/Power/USBCC2: J7.B5 (CC2), R7.1
/Power/USBCD+: D5.3 (I/O2), J7.A6 (D+), J7.B6 (D+)
/Power/USBCD-: D5.1 (I/O1), J7.A7 (D-), J7.B7 (D-)
GND: C2.2, C3.2, C5.2, C6.2, C7.2, C9.2, C10.2, C11.2, C13.2, C14.2, D3.2 (A), D5.2 (GND), D6.1 (K), J6.2, J7.A1 (GND), J7.A12 (GND), J7.B1 (GND), J7.B12 (GND), J7.S1 (SHIELD), Q2.2 (E), R5.2, R6.2, R7.2, R12.2, TP3.1 (1_1), U1.4 (GND), U2.2 (GND); also elsewhere on the board
unnamed: R1.2, U1.8 (BS)

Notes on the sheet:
RESISTORS: 62,5mW WHERE NOT SPECIFIED
R_{H} = (V_{OUT} - 0,6V) * R_{L} / 0,6V V_{OUT} = (0,6 * R_{H} / R_{L}) + 0,6 V_{OUT} = (0,6 * 100k/22,1k) +0,6 V_{OUT} = 3,31V
R_{2} = R_{1}/(V_{OUT} / 0,805 - 1) V_{OUT} = (R_{1} / R_{2}) + 1) * 0,805 V_{OUT} = (300k / 52,3k + 1) * 0,805 V_{OUT} = 5,42V
SHUNT R3 USED FOR CURRENT SENSING DURING DEVELOPMENT. CAN BE REMOVED FROM PRODUCTION BATCHES.
V_{F} = 1,8V @ 2,5mA I_{LED} = (3.3V - V_{F}) / R I_{LED} = (3.3V - 1.8V) / 680R I_{LED} = 2,20 mA
24VDC

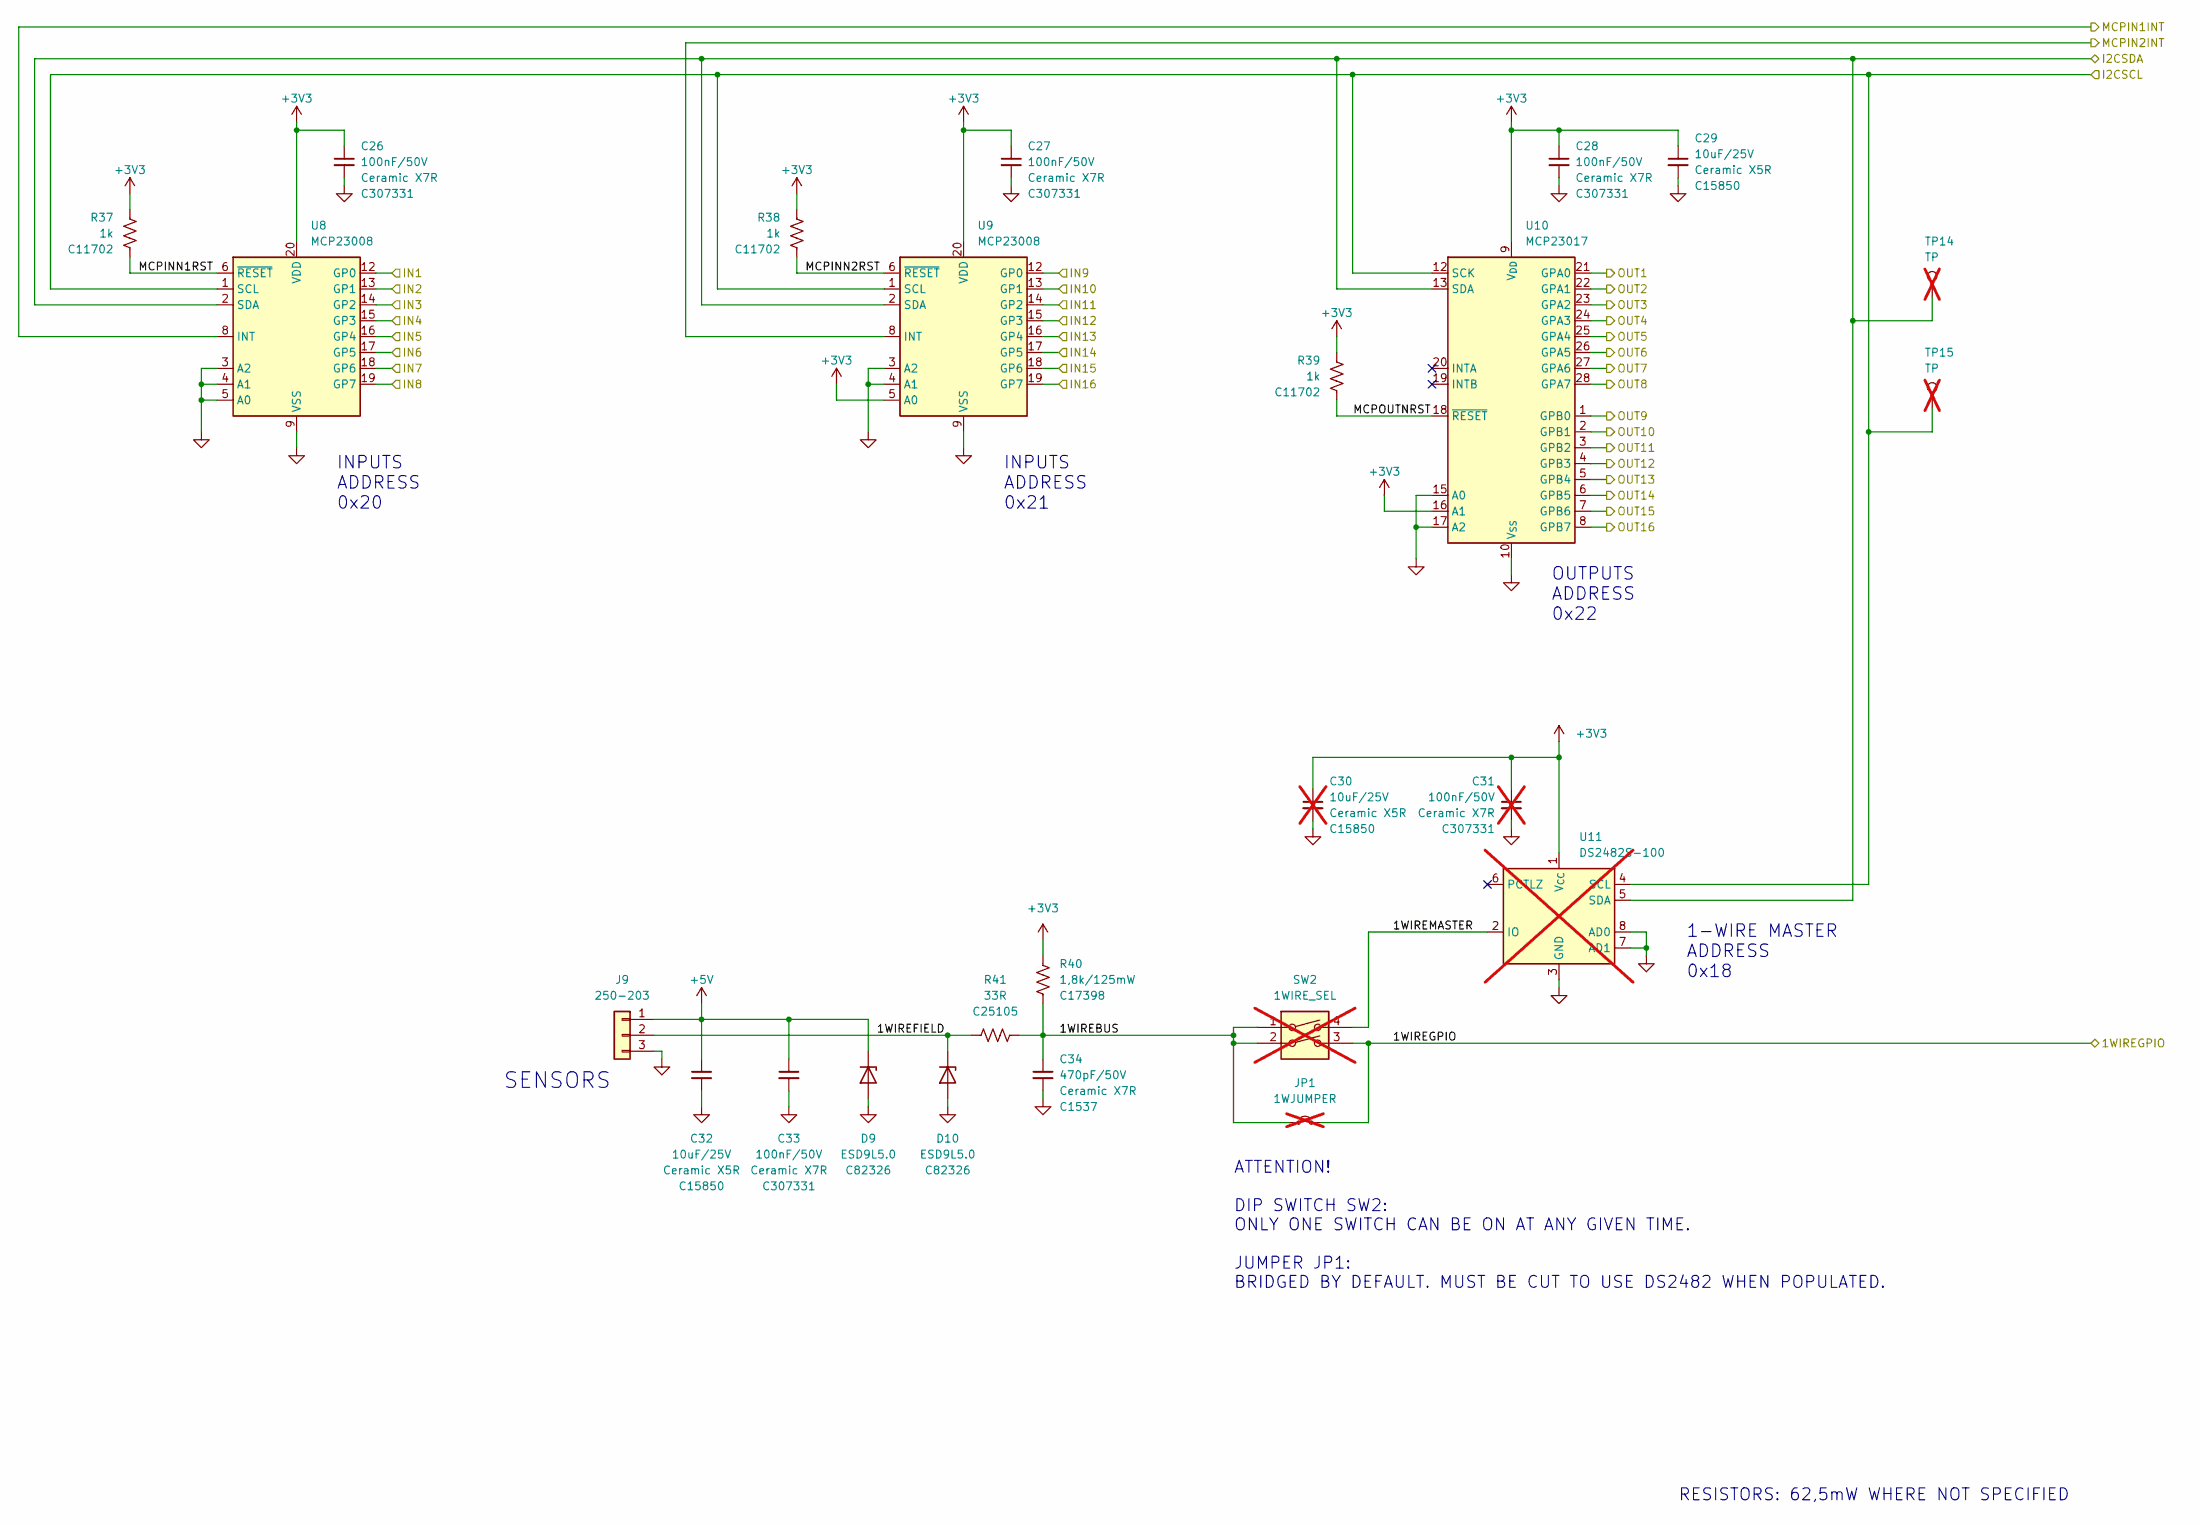
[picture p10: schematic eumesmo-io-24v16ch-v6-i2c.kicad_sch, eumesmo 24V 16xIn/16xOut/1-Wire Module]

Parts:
C26, C27, C28, C33: 100nF/50V; C_0402_1005Metric; Mfr PN CL05B104KB54PNC; LCSC Part # C307331
C29, C32: 10uF/25V; C_0805_2012Metric; Mfr PN CL21A106KAYNNNE; LCSC Part # C15850
C30: 10uF/25V; C_0805_2012Metric; Mfr PN CL21A106KAYNNNE; LCSC Part # C15850; not fitted
C31: 100nF/50V; C_0402_1005Metric; Mfr PN CL05B104KB54PNC; LCSC Part # C307331; not fitted
C34: 470pF/50V; C_0402_1005Metric; Mfr PN 0402B471K500NT; LCSC Part # C1537
D9, D10: ESD9L5.0; D_SOD-923; Mfr PN ESD9L5.0ST5G; LCSC Part # C82326
J9: 250-203; TerminalBlock_Wago_250-203_1x03_P3.5mm_45Degree; Mfr PN 250-203; LCSC Part # C2765062
JP1: 1WJUMPER; SolderJumper-2_P1.3mm_Bridged_RoundedPad1.0x1.5mm; not fitted
R37, R38, R39: 1k; R_0402_1005Metric; Mfr PN 0402WGF1001TCE; LCSC Part # C11702
R40: 1,8k/125mW; R_0805_2012Metric; Mfr PN 0805W8F1801T5E; LCSC Part # C17398
R41: 33R; R_0402_1005Metric; Mfr PN 0402WGF330JTCE; LCSC Part # C25105
SW2: 1WIRE_SEL; SW_DIP_SPSTx02_Slide_Copal_CHS-02B_W7.62mm_P1.27mm; Mfr PN DSHP02TS-S; LCSC Part # C319052; not fitted
TP14, TP15: TP; TestPoint_Pad_D1.5mm; not fitted
U8, U9: MCP23008; SSOP-20_5.3x7.2mm_P0.65mm; Mfr PN MCP23008-E/SS; LCSC Part # C148011
U10: MCP23017; SSOP-28_5.3x10.2mm_P0.65mm; Mfr PN MCP23017-E/SS; LCSC Part # C506653
U11: DS2482S-100; SO-8_3.9x4.9mm_P1.27mm; Mfr PN DS2482S-100; LCSC Part # C143306; not fitted

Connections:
+3V3: C26.1, C27.1, C28.1, C29.1, C30.1, C31.1, R37.1, R38.1, R39.1, R40.1, U8.20 (VDD), U9.5 (A0), U9.20 (VDD), U10.9 (V_{DD}), U10.16 (A1), U11.1 (V_{CC}); also elsewhere on the board
+5V: C32.1, C33.1, D9.1 (K), J9.1; also elsewhere on the board
/I2C Devices/1WIREBUS: C34.1, JP1.1 (A), R40.2, R41.2, SW2.1, SW2.2
/I2C Devices/1WIREFIELD: D10.1 (K), J9.2, R41.1
/I2C Devices/1WIREGPIO: JP1.2 (B), SW2.3; also elsewhere on the board
/I2C Devices/1WIREMASTER: SW2.4, U11.2 (IO)
/I2C Devices/I2CSCL: TP15.1, U8.1 (SCL), U9.1 (SCL), U10.12 (SCK), U11.4 (SCL); also elsewhere on the board
/I2C Devices/I2CSDA: TP14.1, U8.2 (SDA), U9.2 (SDA), U10.13 (SDA), U11.5 (SDA); also elsewhere on the board
/I2C Devices/MCPIN1INT: U8.8 (INT); also elsewhere on the board
/I2C Devices/MCPIN2INT: U9.8 (INT); also elsewhere on the board
/I2C Devices/MCPINN1RST: R37.2, U8.6 (~RESET)
/I2C Devices/MCPINN2RST: R38.2, U9.6 (~RESET)
/I2C Devices/MCPOUTNRST: R39.2, U10.18 (~RESET)
/INPUT1: U8.12 (GP0); also elsewhere on the board
/INPUT2: U8.13 (GP1); also elsewhere on the board
/INPUT3: U8.14 (GP2); also elsewhere on the board
/INPUT4: U8.15 (GP3); also elsewhere on the board
/INPUT5: U8.16 (GP4); also elsewhere on the board
/INPUT6: U8.17 (GP5); also elsewhere on the board
/INPUT7: U8.18 (GP6); also elsewhere on the board
/INPUT8: U8.19 (GP7); also elsewhere on the board
/INPUT9: U9.12 (GP0); also elsewhere on the board
/INPUT10: U9.13 (GP1); also elsewhere on the board
/INPUT11: U9.14 (GP2); also elsewhere on the board
/INPUT12: U9.15 (GP3); also elsewhere on the board
/INPUT13: U9.16 (GP4); also elsewhere on the board
/INPUT14: U9.17 (GP5); also elsewhere on the board
/INPUT15: U9.18 (GP6); also elsewhere on the board
/INPUT16: U9.19 (GP7); also elsewhere on the board
/OUTPUT1: U10.21 (GPA0); also elsewhere on the board
/OUTPUT2: U10.22 (GPA1); also elsewhere on the board
/OUTPUT3: U10.23 (GPA2); also elsewhere on the board
/OUTPUT4: U10.24 (GPA3); also elsewhere on the board
/OUTPUT5: U10.25 (GPA4); also elsewhere on the board
/OUTPUT6: U10.26 (GPA5); also elsewhere on the board
/OUTPUT7: U10.27 (GPA6); also elsewhere on the board
/OUTPUT8: U10.28 (GPA7); also elsewhere on the board
/OUTPUT9: U10.1 (GPB0); also elsewhere on the board
/OUTPUT10: U10.2 (GPB1); also elsewhere on the board
/OUTPUT11: U10.3 (GPB2); also elsewhere on the board
/OUTPUT12: U10.4 (GPB3); also elsewhere on the board
/OUTPUT13: U10.5 (GPB4); also elsewhere on the board
/OUTPUT14: U10.6 (GPB5); also elsewhere on the board
/OUTPUT15: U10.7 (GPB6); also elsewhere on the board
/OUTPUT16: U10.8 (GPB7); also elsewhere on the board
GND: C26.2, C27.2, C28.2, C29.2, C30.2, C31.2, C32.2, C33.2, C34.2, D9.2 (A), D10.2 (A), J9.3, U8.3 (A2), U8.4 (A1), U8.5 (A0), U8.9 (VSS), U9.3 (A2), U9.4 (A1), U9.9 (VSS), U10.10 (V_{SS}), U10.15 (A0), U10.17 (A2), U11.3 (GND), U11.7 (AD1), U11.8 (AD0); also elsewhere on the board

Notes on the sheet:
OUTPUTS ADDRESS 0x22
INPUTS ADDRESS 0x20
RESISTORS: 62,5mW WHERE NOT SPECIFIED
1-WIRE MASTER ADDRESS 0x18
INPUTS ADDRESS 0x21
ATTENTION! DIP SWITCH SW2: ONLY ONE SWITCH CAN BE ON AT ANY GIVEN TIME. JUMPER JP1: BRIDGED BY DEFAULT. MUST BE CUT TO USE DS2482 WHEN POPULATED.
SENSORS

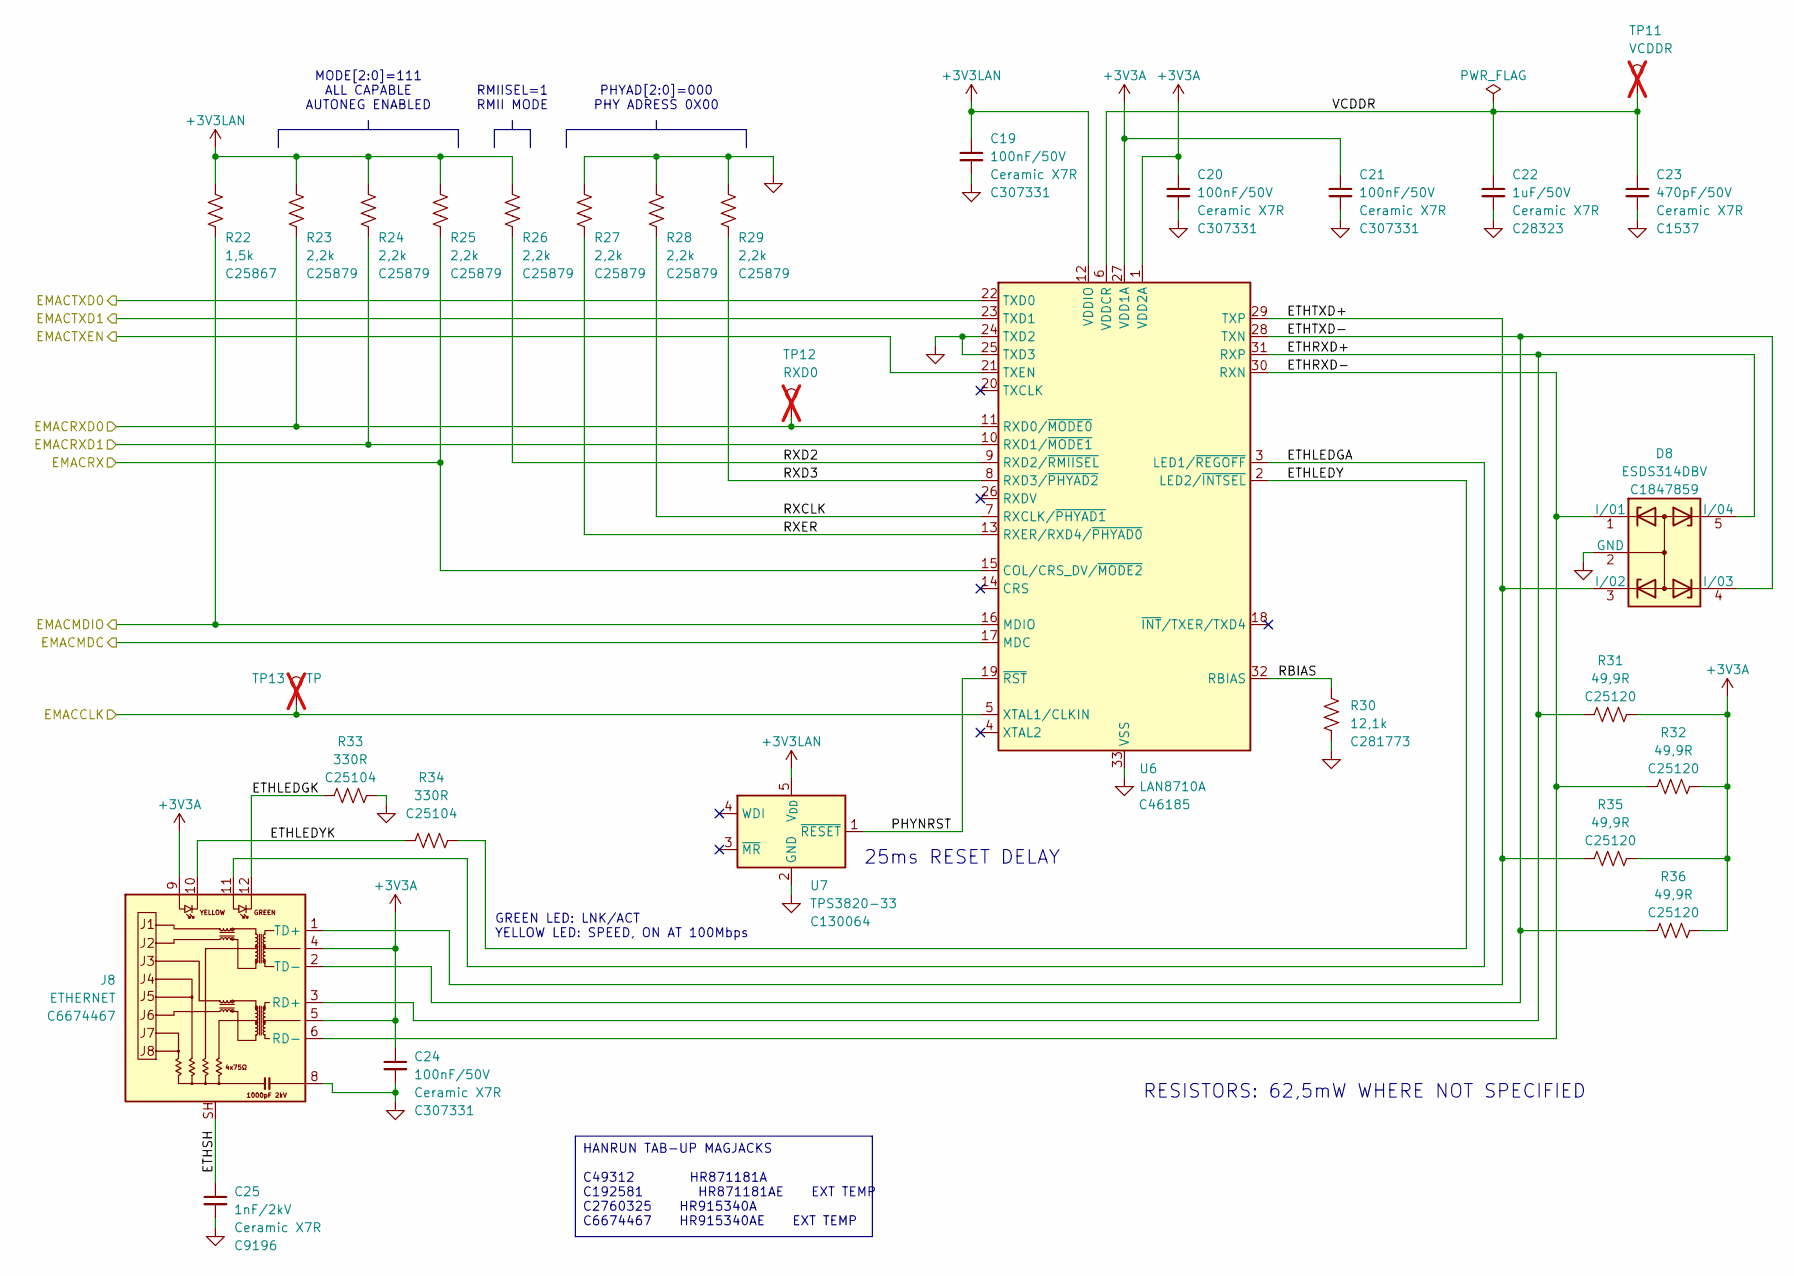
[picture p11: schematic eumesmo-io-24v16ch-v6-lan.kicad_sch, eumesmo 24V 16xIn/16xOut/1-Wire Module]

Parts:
C19, C20, C21, C24: 100nF/50V; C_0402_1005Metric; Mfr PN CL05B104KB54PNC; LCSC Part # C307331
C22: 1uF/50V; C_0805_2012Metric; Mfr PN CL21B105KBFNNNE; LCSC Part # C28323
C23: 470pF/50V; C_0402_1005Metric; Mfr PN 0402B471K500NT; LCSC Part # C1537
C25: 1nF/2kV; C_1206_3216Metric; Mfr PN 1206B102K202NT; LCSC Part # C9196
D8: ESDS314DBV; SOT-23-5; Mfr PN ESDS314DBVR; LCSC Part # C1847859
J8: ETHERNET; RJ45_HanRun_HR915340A; Mfr PN HR915340AE; LCSC Part # C6674467
R22: 1,5k; R_0402_1005Metric; Mfr PN 0402WGF1501TCE; LCSC Part # C25867
R23, R24, R25, R26, R27, R28, R29: 2,2k; R_0402_1005Metric; Mfr PN 0402WGF2201TCE; LCSC Part # C25879
R30: 12,1k; R_0402_1005Metric; Mfr PN RT0402BRD0712K1L; LCSC Part # C281773
R31, R32, R35, R36: 49,9R; R_0402_1005Metric; Mfr PN 0402WGF499JTCE; LCSC Part # C25120
R33, R34: 330R; R_0402_1005Metric; Mfr PN 0402WGF3300TCE; LCSC Part # C25104
TP11: VCDDR; TestPoint_Pad_D1.5mm; not fitted
TP12: RXD0; TestPoint_Pad_D1.5mm; not fitted
TP13: TP; TestPoint_Pad_D1.5mm; not fitted
U6: LAN8710A; QFN-32-1EP_5x5mm_P0.5mm_EP3.3x3.3mm_ThermalVias; Mfr PN LAN8710A-EZC-TR; LCSC Part # C46185
U7: TPS3820-33; SOT-23-5; Mfr PN TPS3820-33DBVR; LCSC Part # C130064

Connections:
+3V3A: C20.1, C21.1, C24.1, J8.4, J8.5, J8.9, R31.2, R32.2, R35.2, R36.2, U6.1 (VDD2A), U6.27 (VDD1A); also elsewhere on the board
+3V3LAN: C19.1, R22.1, R23.1, R24.1, R25.1, R26.1, U6.12 (VDDIO), U7.5 (V_{DD}); also elsewhere on the board
/LAN/EMACCLK: TP13.1, U6.5 (XTAL1/CLKIN); also elsewhere on the board
/LAN/EMACMDC: U6.17 (MDC); also elsewhere on the board
/LAN/EMACMDIO: R22.2, U6.16 (MDIO); also elsewhere on the board
/LAN/EMACRX: R25.2, U6.15 (COL/CRS_DV/~MODE2); also elsewhere on the board
/LAN/EMACRXD0: R23.2, U6.11 (RXD0/~MODE0); also elsewhere on the board
/LAN/EMACRXD1: R24.2, U6.10 (RXD1/~MODE1); also elsewhere on the board
/LAN/EMACTXD0: U6.22 (TXD0); also elsewhere on the board
/LAN/EMACTXD1: U6.23 (TXD1); also elsewhere on the board
/LAN/EMACTXEN: U6.21 (TXEN); also elsewhere on the board
/LAN/ETHLEDGA: J8.11, U6.3 (LED1/~REGOFF)
/LAN/ETHLEDGK: J8.12, R33.1
/LAN/ETHLEDY: R34.2, U6.2 (LED2/~INTSEL)
/LAN/ETHLEDYK: J8.10, R34.1
/LAN/ETHRXD+: D8.5 (I/04), J8.3 (RD+), R31.1, U6.31 (RXP)
/LAN/ETHRXD-: D8.1 (I/01), J8.6 (RD-), R32.1, U6.30 (RXN)
/LAN/ETHSH: C25.1, J8.SH
/LAN/ETHTXD+: D8.3 (I/02), J8.1 (TD+), R35.1, U6.29 (TXP)
/LAN/ETHTXD-: D8.4 (I/03), J8.2 (TD-), R36.1, U6.28 (TXN)
/LAN/PHYNRST: U6.19 (~RST), U7.1 (~RESET)
/LAN/RBIAS: R30.1, U6.32 (RBIAS)
/LAN/RXCLK: R28.2, U6.7 (RXCLK/~PHYAD1)
/LAN/RXD2: R26.2, U6.9 (RXD2/~RMIISEL)
/LAN/RXD3: R29.2, U6.8 (RXD3/~PHYAD2)
/LAN/RXER: R27.2, U6.13 (RXER/RXD4/~PHYAD0)
/LAN/VCDDR: C22.1, C23.1, U6.6 (VDDCR)
GND: C19.2, C20.2, C21.2, C22.2, C23.2, C24.2, C25.2, D8.2 (GND), J8.8, R27.1, R28.1, R29.1, R30.2, R33.2, U6.24 (TXD2), U6.25 (TXD3), U6.33 (VSS), U7.2 (GND); also elsewhere on the board

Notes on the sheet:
25ms RESET DELAY
GREEN LED: LNK/ACT YELLOW LED: SPEED, ON AT 100Mbps
MODE[2:0]=111 ALL CAPABLE AUTONEG ENABLED
PHYAD[2:0]=000 PHY ADRESS 0X00
RMIISEL=1 RMII MODE
RESISTORS: 62,5mW WHERE NOT SPECIFIED
HANRUN TAB-UP MAGJACKS C49312 HR871181A C192581 HR871181AE EXT TEMP C2760325 HR915340A C6674467 HR915340AE EXT TEMP

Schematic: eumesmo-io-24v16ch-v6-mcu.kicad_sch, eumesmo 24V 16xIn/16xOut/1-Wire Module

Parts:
C15, C17: 10uF/25V; C_0805_2012Metric; Mfr PN CL21A106KAYNNNE; LCSC Part # C15850
C16, C18: 100nF/50V; C_0402_1005Metric; Mfr PN CL05B104KB54PNC; LCSC Part # C307331
D7: ORANGE/0603; LED_0603_1608Metric; Mfr PN 19-217/S2C-AL1M2VY/6T; LCSC Part # C2987557
Q3: UMH3N; SOT-363_SC-70-6; Mfr PN UMH3N; LCSC Part # C62892
R13: 680R; R_0402_1005Metric; Mfr PN 0402WGF6800TCE; LCSC Part # C25130
R14, R15, R18: 10k; R_0402_1005Metric; Mfr PN RC0402FR-0710KL; LCSC Part # C60490
R16, R17, R20, R21: 2,2k; R_0402_1005Metric; Mfr PN 0402WGF2201TCE; LCSC Part # C25879
R19: 33R; R_0402_1005Metric; Mfr PN 0402WGF330JTCE; LCSC Part # C25105
SW1: RESET; SW_SPST_Xunpu_TS1088AR02016; Mfr PN TS-1088-AR02016; LCSC Part # C720477
TP9, TP10: TP; TestPoint_Pad_D1.5mm; not fitted
U3: TPS3820-33; SOT-23-5; Mfr PN TPS3820-33DBVR; LCSC Part # C130064
U4: CH340K; SSOP-10-1EP_3.9x4.9mm_P1mm_EP2.1x3.3mm; Mfr PN CH340K; LCSC Part # C968586
U5: ESP32-WROOM-32UE-N16; ESP32-WROOM-32U; Mfr PN ESP32-WROOM-32UE-N16; LCSC Part # C701346

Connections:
+3V3: C15.1, C16.1, C17.1, C18.1, R14.1, R15.1, R16.1, R17.1, R20.1, R21.1, U3.5 (V_{DD}), U4.7 (VCC), U4.10 (V3), U5.2 (VDD); also elsewhere on the board
/I2C Devices/1WIREGPIO: U5.27 (IO16); also elsewhere on the board
/I2C Devices/I2CSCL: R20.2, U5.8 (IO32); also elsewhere on the board
/I2C Devices/I2CSDA: R21.2, U5.9 (IO33); also elsewhere on the board
/I2C Devices/MCPIN1INT: R16.2, U5.16 (IO13); also elsewhere on the board
/I2C Devices/MCPIN2INT: R17.2, U5.13 (IO14); also elsewhere on the board
/LAN/EMACCLK: R19.2, U5.5 (SENSOR_VN); also elsewhere on the board
/LAN/EMACMDC: U5.37 (IO23); also elsewhere on the board
/LAN/EMACMDIO: U5.30 (IO18); also elsewhere on the board
/LAN/EMACRX: U5.12 (IO27); also elsewhere on the board
/LAN/EMACRXD0: U5.10 (IO25); also elsewhere on the board
/LAN/EMACRXD1: U5.11 (IO26); also elsewhere on the board
/LAN/EMACTXD0: U5.31 (IO19); also elsewhere on the board
/LAN/EMACTXD1: U5.36 (IO22); also elsewhere on the board
/LAN/EMACTXEN: U5.33 (IO21); also elsewhere on the board
/MCU/CPULED: D7.2 (A), R13.2
/MCU/CPUOK: R13.1, U5.24 (IO2)
/MCU/ESPCLK: R19.1, U5.28 (IO17)
/MCU/ESPEN: U3.1 (~RESET), U5.3 (EN)
/MCU/ESPPROG: Q3.3 (C2), R15.2, U5.25 (IO0)
/MCU/MRESET: Q3.6 (C1), R14.2, SW1.2, U3.3 (~MR)
/MCU/PHYPWR: R18.1, U5.14 (IO12); also elsewhere on the board
/MCU/UARTNDTR: Q3.2 (B1), Q3.4 (E2), U4.4 (~DTR)
/MCU/UARTNRTS: Q3.1 (E1), Q3.5 (B2), U4.6 (~RTS)
/MCU/UARTRXD: U4.9 (RXD), U5.35 (TXD0/IO1)
/MCU/UARTTXD: U4.8 (TXD), U5.34 (RXD0/IO3)
/MCU/USBD+: TP9.1, U4.1 (UD+); also elsewhere on the board
/MCU/USBD-: TP10.1, U4.2 (UD-); also elsewhere on the board
GND: C15.2, C16.2, C17.2, C18.2, D7.1 (K), R18.2, SW1.1, U3.2 (GND), U4.3 (GND), U4.11 (GND), U5.1 (GND), U5.15 (GND), U5.38 (GND), U5.39 (GND); also elsewhere on the board

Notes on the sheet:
TASMOTA CONFIGS The configs below must be applied via terminal/console and adjusted according to the desired hostname, device name, network addresses and behavior of switches. Configure switches: > backlog switchmode1 5; switchmode2 5; switchmode3 5; switchmode4 5; switchmode5 5; switchmode6 5; swi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
25ms RESET DELAY
TEMPLATE FOR GPIO ASSIGNMENT {"NAME":"eumesmo-io-24v16ch-v6","GPIO":[0,3200,0,3232,0,0,0,0,5536,10240,10241,0,1312, 0,5600,0,0,0,0,5568,0,0,0,0,0,0,0,0,608,640,0,0,0,0,0,0],"FLAG":0,"BASE":1} See https://tasmota.github.io/docs/Templates/
TEMPLATE FOR MCP23017 I/O ASSIGNMENT {"NAME":"MCP23017 expanders","BASE":0,"GPIO":[192,193,194,195,196,197,198,199,200,201, 202,203,204,205,206,207,224,225,226,227,228,229,230,231,232,233,234,235,236,237,238, 239],"IOCON":0x5C} Save as mcp23x.dat and load into tasmota's filesystem. See https://tasm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
RESISTORS: 62,5mW WHERE NOT SPECIFIED
V_{F} = 1,8V @ 2,5mA I_{LED} = (3.3V - V_{F}) / R I_{LED} = (3.3V - 1.8V) / 680R I_{LED} = 2,20 mA
ESP32 GPIO ASSIGNMENT PIN PORT FUNCTION COMPONENT 25 GPIO0 AUTO FLASH MODE 0 35 GPIO1 SERIAL TX 3200 24 GPIO2 - 0 34 GPIO3 SERIAL RX 3232 26 GPIO4 - 0 29 GPIO5 - 0 17 GPIO9 - 0 18 GPIO10 - 0 14 GPIO12 ETH POWER 5536 16 GPIO13 MCP23017 INT1 10240 13 GPIO14 MCP23017 INT2 10241 23 GPIO15 - 0 27 GPIO16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

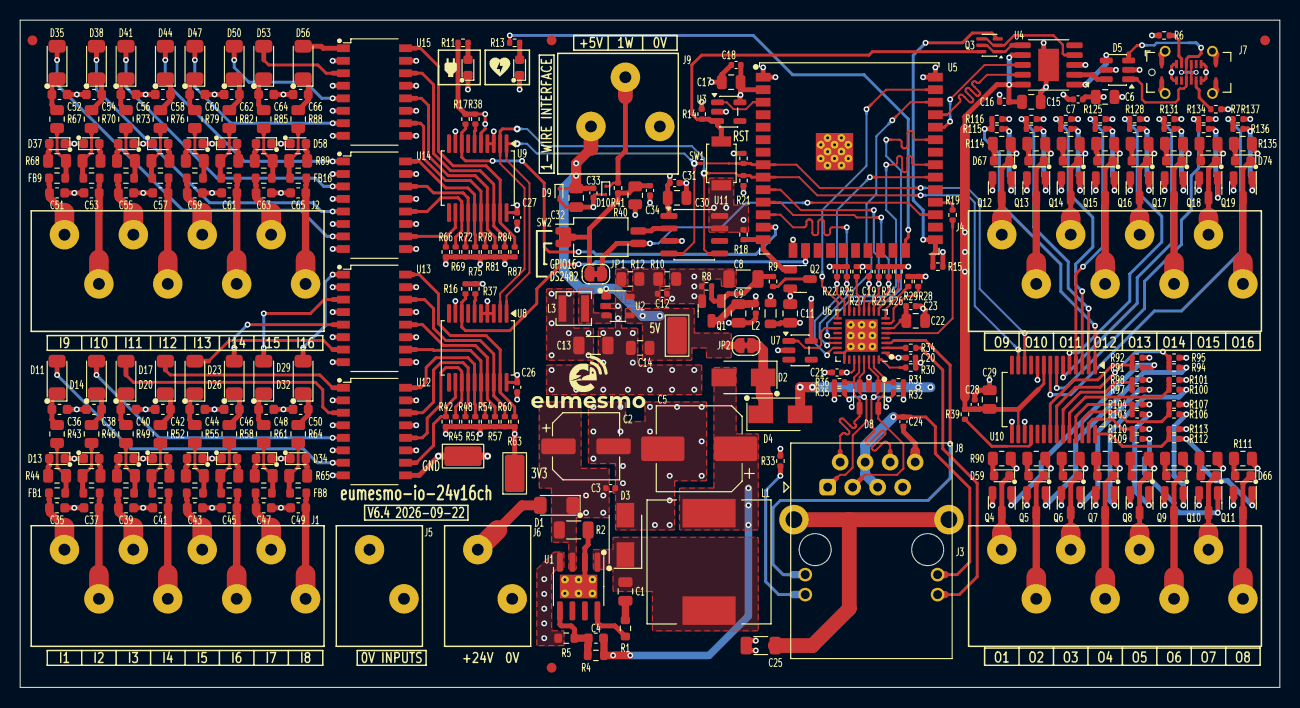
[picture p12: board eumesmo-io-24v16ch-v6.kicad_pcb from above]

Board: 4 copper layers, 128.0 x 67.8 mm, 333 parts (0 on the bottom side), 234 nets.

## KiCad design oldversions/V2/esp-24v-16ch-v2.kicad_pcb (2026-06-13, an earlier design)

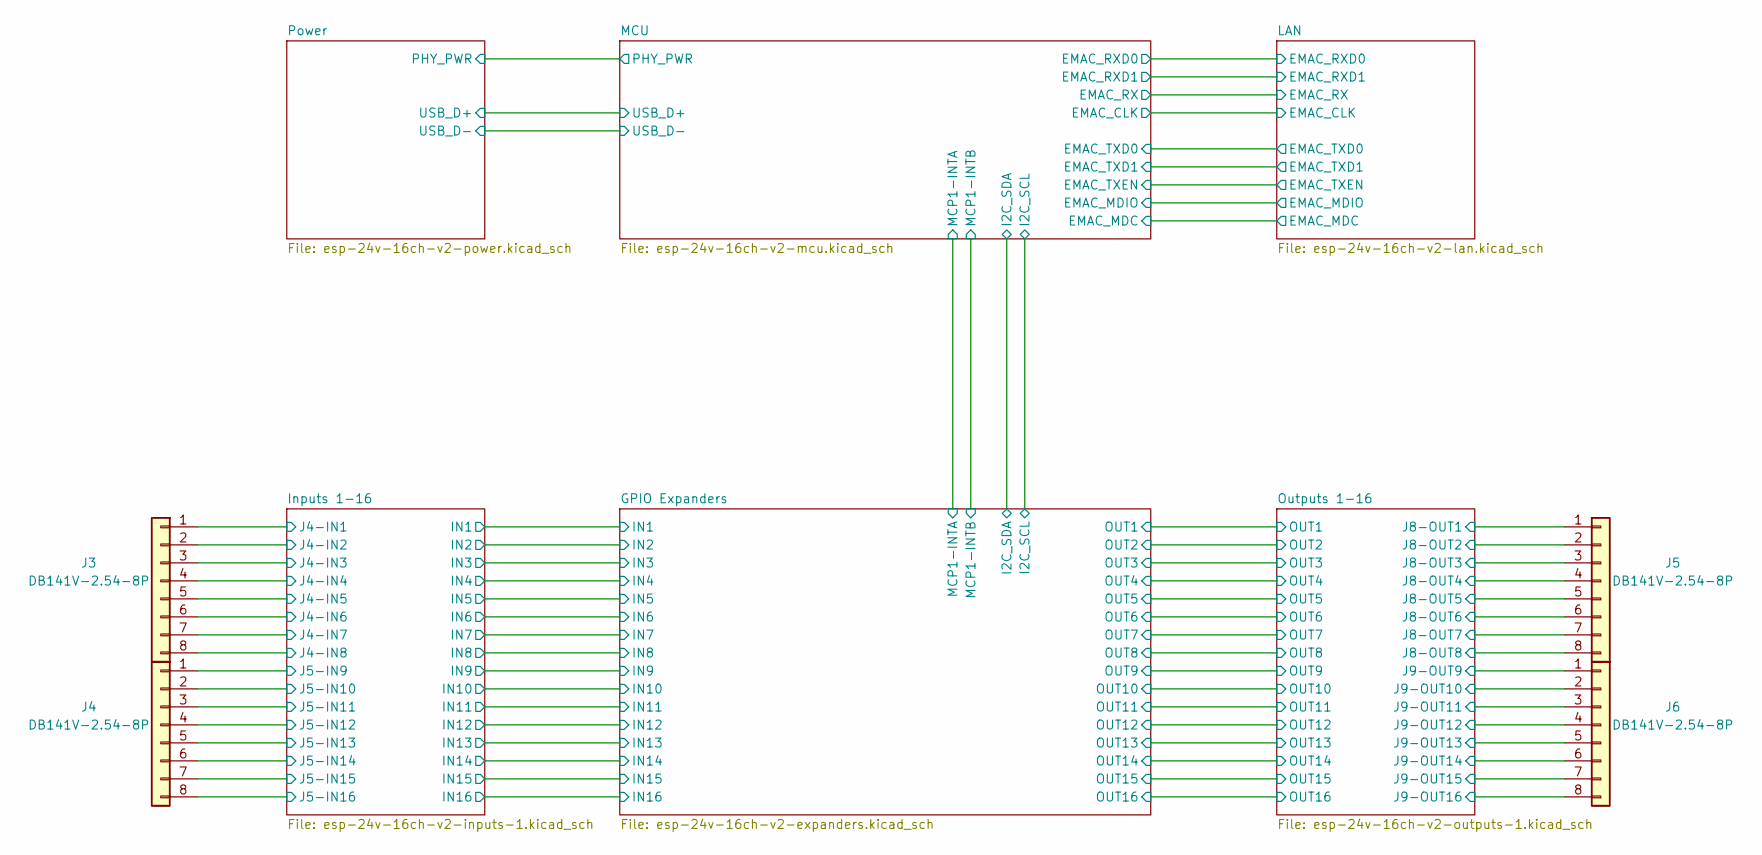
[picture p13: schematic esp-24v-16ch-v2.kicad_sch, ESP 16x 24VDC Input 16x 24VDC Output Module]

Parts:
J3, J4, J5, J6: DB141V-2.54-8P; TerminalBlock_Dibo_DB141V-2.54-8P_1x08_P2.54mm_Vertical; Mfr PN DB141V-2.54-8P; JLCPCB BOM 1

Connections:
/Inputs 1-16/J4-IN1: J3.1; also elsewhere on the board
/Inputs 1-16/J4-IN2: J3.2; also elsewhere on the board
/Inputs 1-16/J4-IN3: J3.3; also elsewhere on the board
/Inputs 1-16/J4-IN4: J3.4; also elsewhere on the board
/Inputs 1-16/J4-IN5: J3.5; also elsewhere on the board
/Inputs 1-16/J4-IN6: J3.6; also elsewhere on the board
/Inputs 1-16/J4-IN7: J3.7; also elsewhere on the board
/Inputs 1-16/J4-IN8: J3.8; also elsewhere on the board
/Inputs 1-16/J5-IN9: J4.1; also elsewhere on the board
/Inputs 1-16/J5-IN10: J4.2; also elsewhere on the board
/Inputs 1-16/J5-IN11: J4.3; also elsewhere on the board
/Inputs 1-16/J5-IN12: J4.4; also elsewhere on the board
/Inputs 1-16/J5-IN13: J4.5; also elsewhere on the board
/Inputs 1-16/J5-IN14: J4.6; also elsewhere on the board
/Inputs 1-16/J5-IN15: J4.7; also elsewhere on the board
/Inputs 1-16/J5-IN16: J4.8; also elsewhere on the board
/Outputs 1-16/J8-OUT1: J5.1; also elsewhere on the board
/Outputs 1-16/J8-OUT2: J5.2; also elsewhere on the board
/Outputs 1-16/J8-OUT3: J5.3; also elsewhere on the board
/Outputs 1-16/J8-OUT4: J5.4; also elsewhere on the board
/Outputs 1-16/J8-OUT5: J5.5; also elsewhere on the board
/Outputs 1-16/J8-OUT6: J5.6; also elsewhere on the board
/Outputs 1-16/J8-OUT7: J5.7; also elsewhere on the board
/Outputs 1-16/J8-OUT8: J5.8; also elsewhere on the board
/Outputs 1-16/J9-OUT9: J6.1; also elsewhere on the board
/Outputs 1-16/J9-OUT10: J6.2; also elsewhere on the board
/Outputs 1-16/J9-OUT11: J6.3; also elsewhere on the board
/Outputs 1-16/J9-OUT12: J6.4; also elsewhere on the board
/Outputs 1-16/J9-OUT13: J6.5; also elsewhere on the board
/Outputs 1-16/J9-OUT14: J6.6; also elsewhere on the board
/Outputs 1-16/J9-OUT15: J6.7; also elsewhere on the board
/Outputs 1-16/J9-OUT16: J6.8; also elsewhere on the board

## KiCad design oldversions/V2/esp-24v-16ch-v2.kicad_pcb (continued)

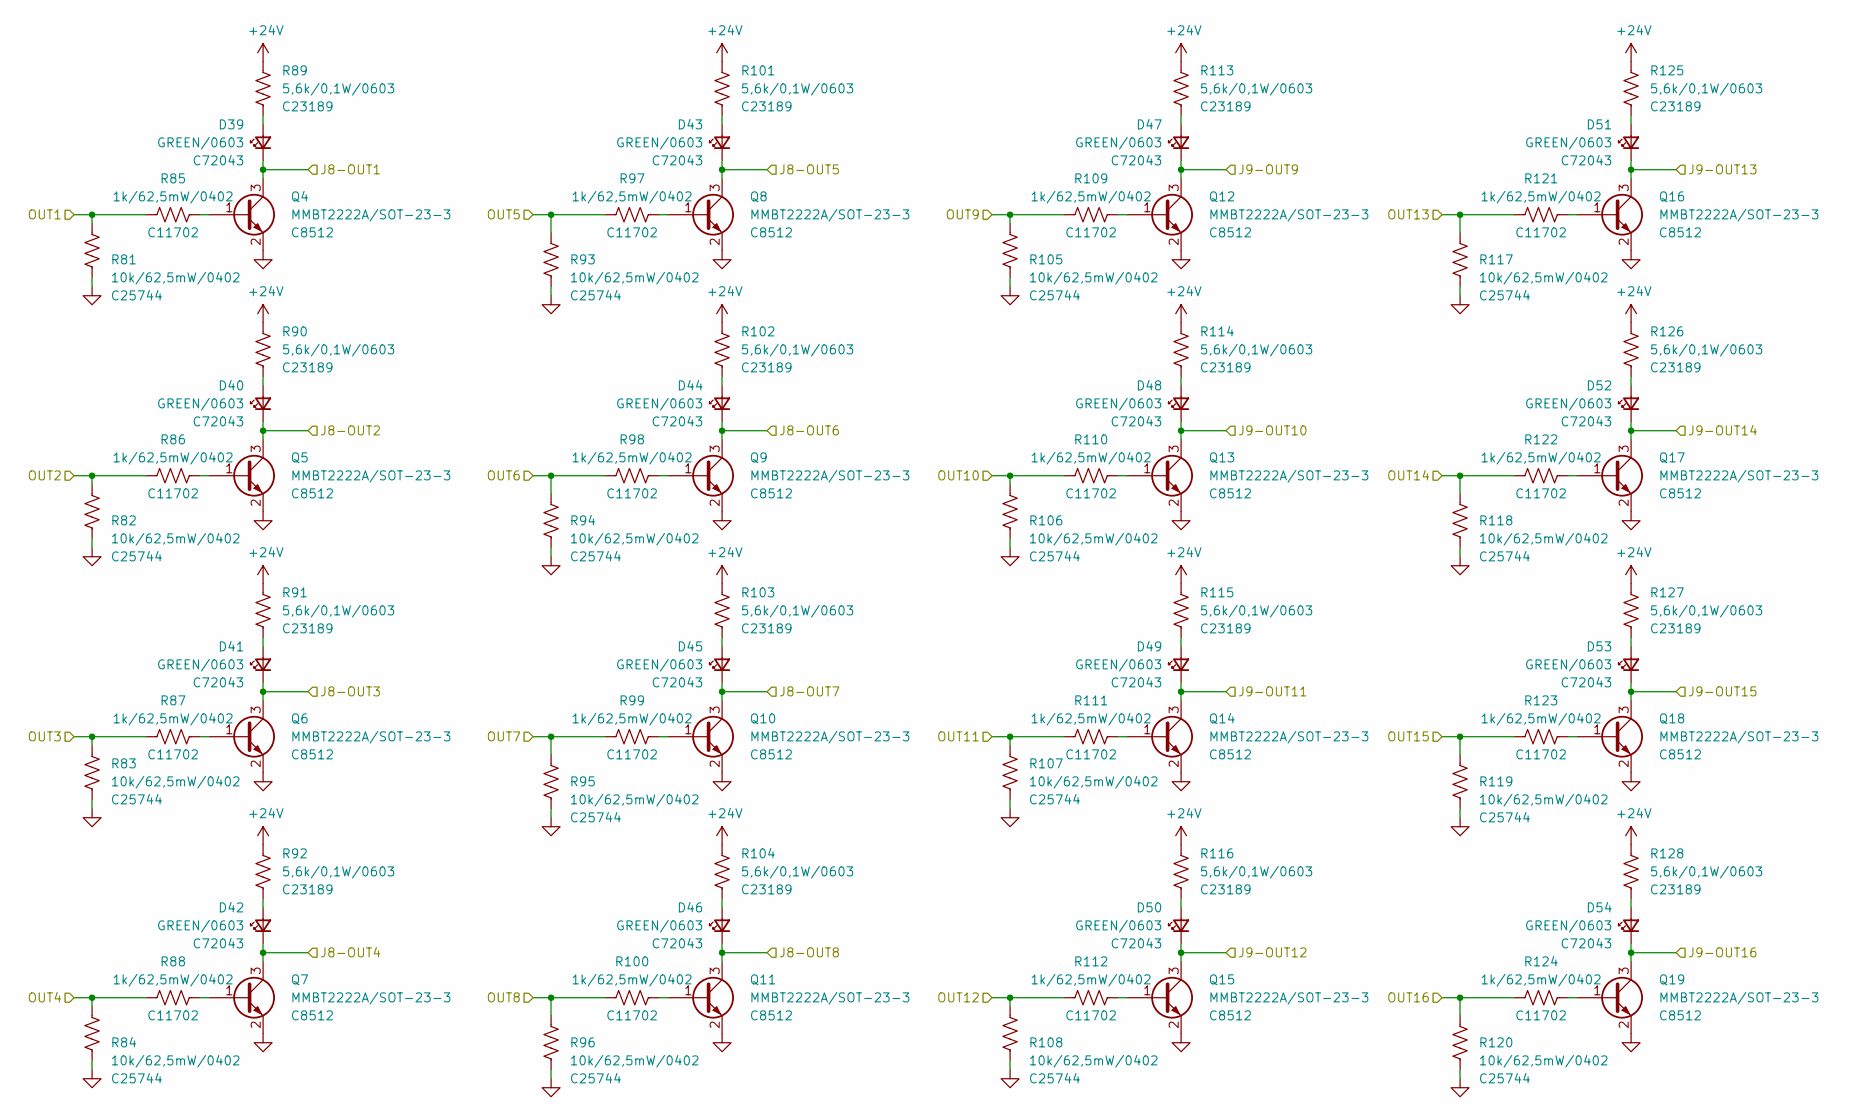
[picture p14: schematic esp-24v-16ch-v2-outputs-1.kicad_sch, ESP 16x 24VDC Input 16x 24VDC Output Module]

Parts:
D39, D40, D41, D42, D43, D44, D45, D46, D47, D48, D49, D50, D51, D52, D53, D54: GREEN/0603; LED_0603_1608Metric; Mfr PN 19-217/GHC-YR1S2/3T; LCSC Part # C72043
Q4, Q5, Q6, Q7, Q8, Q9, Q10, Q11, Q12, Q13, Q14, Q15, Q16, Q17, Q18, Q19: MMBT2222A/SOT-23-3; SOT-23; Mfr PN MMBT2222A; JLCPCB BOM 1
R81, R82, R83, R84, R93, R94, R95, R96, R105, R106, R107, R108, R117, R118, R119, R120: 10k/62,5mW/0402; R_0402_1005Metric; Mfr PN 0402WGF1002TCE; LCSC Part # C25744
R85, R86, R87, R88, R97, R98, R99, R100, R109, R110, R111, R112, R121, R122, R123, R124: 1k/62,5mW/0402; R_0402_1005Metric; Mfr PN 0402WGF1001TCE; LCSC Part # C11702
R89, R90, R91, R92, R101, R102, R103, R104, R113, R114, R115, R116, R125, R126, R127, R128: 5,6k/0,1W/0603; R_0603_1608Metric; Mfr PN 0603WAF5601T5E; LCSC Part # C23189

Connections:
+24V: R89.1, R90.1, R91.1, R92.1, R101.1, R102.1, R103.1, R104.1, R113.1, R114.1, R115.1, R116.1, R125.1, R126.1, R127.1, R128.1; also elsewhere on the board
/GPIO Expanders/OUT1: R81.1, R85.2; also elsewhere on the board
/GPIO Expanders/OUT2: R82.1, R86.2; also elsewhere on the board
/GPIO Expanders/OUT3: R83.1, R87.2; also elsewhere on the board
/GPIO Expanders/OUT4: R84.1, R88.2; also elsewhere on the board
/GPIO Expanders/OUT5: R93.1, R97.2; also elsewhere on the board
/GPIO Expanders/OUT6: R94.1, R98.2; also elsewhere on the board
/GPIO Expanders/OUT7: R95.1, R99.2; also elsewhere on the board
/GPIO Expanders/OUT8: R96.1, R100.2; also elsewhere on the board
/GPIO Expanders/OUT9: R105.1, R109.2; also elsewhere on the board
/GPIO Expanders/OUT10: R106.1, R110.2; also elsewhere on the board
/GPIO Expanders/OUT11: R107.1, R111.2; also elsewhere on the board
/GPIO Expanders/OUT12: R108.1, R112.2; also elsewhere on the board
/GPIO Expanders/OUT13: R117.1, R121.2; also elsewhere on the board
/GPIO Expanders/OUT14: R118.1, R122.2; also elsewhere on the board
/GPIO Expanders/OUT15: R119.1, R123.2; also elsewhere on the board
/GPIO Expanders/OUT16: R120.1, R124.2; also elsewhere on the board
/Outputs 1-16/J8-OUT1: D39.1 (K), Q4.3 (C); also elsewhere on the board
/Outputs 1-16/J8-OUT2: D40.1 (K), Q5.3 (C); also elsewhere on the board
/Outputs 1-16/J8-OUT3: D41.1 (K), Q6.3 (C); also elsewhere on the board
/Outputs 1-16/J8-OUT4: D42.1 (K), Q7.3 (C); also elsewhere on the board
/Outputs 1-16/J8-OUT5: D43.1 (K), Q8.3 (C); also elsewhere on the board
/Outputs 1-16/J8-OUT6: D44.1 (K), Q9.3 (C); also elsewhere on the board
/Outputs 1-16/J8-OUT7: D45.1 (K), Q10.3 (C); also elsewhere on the board
/Outputs 1-16/J8-OUT8: D46.1 (K), Q11.3 (C); also elsewhere on the board
/Outputs 1-16/J9-OUT9: D47.1 (K), Q12.3 (C); also elsewhere on the board
/Outputs 1-16/J9-OUT10: D48.1 (K), Q13.3 (C); also elsewhere on the board
/Outputs 1-16/J9-OUT11: D49.1 (K), Q14.3 (C); also elsewhere on the board
/Outputs 1-16/J9-OUT12: D50.1 (K), Q15.3 (C); also elsewhere on the board
/Outputs 1-16/J9-OUT13: D51.1 (K), Q16.3 (C); also elsewhere on the board
/Outputs 1-16/J9-OUT14: D52.1 (K), Q17.3 (C); also elsewhere on the board
/Outputs 1-16/J9-OUT15: D53.1 (K), Q18.3 (C); also elsewhere on the board
/Outputs 1-16/J9-OUT16: D54.1 (K), Q19.3 (C); also elsewhere on the board
GND: Q4.2 (E), Q5.2 (E), Q6.2 (E), Q7.2 (E), Q8.2 (E), Q9.2 (E), Q10.2 (E), Q11.2 (E), Q12.2 (E), Q13.2 (E), Q14.2 (E), Q15.2 (E), Q16.2 (E), Q17.2 (E), Q18.2 (E), Q19.2 (E), R81.2, R82.2, R83.2, R84.2, R93.2, R94.2, R95.2, R96.2, R105.2, R106.2, R107.2, R108.2, R117.2, R118.2, R119.2, R120.2; also elsewhere on the board
unnamed: D39.2 (A), R89.2
unnamed: D40.2 (A), R90.2
unnamed: D41.2 (A), R91.2
unnamed: D42.2 (A), R92.2
unnamed: D43.2 (A), R101.2
unnamed: D44.2 (A), R102.2
unnamed: D45.2 (A), R103.2
unnamed: D46.2 (A), R104.2
unnamed: D47.2 (A), R113.2
unnamed: D48.2 (A), R114.2
unnamed: D49.2 (A), R115.2
unnamed: D50.2 (A), R116.2
unnamed: D51.2 (A), R125.2
unnamed: D52.2 (A), R126.2
unnamed: D53.2 (A), R127.2
unnamed: D54.2 (A), R128.2
unnamed: Q4.1 (B), R85.1
unnamed: Q5.1 (B), R86.1
unnamed: Q6.1 (B), R87.1
unnamed: Q7.1 (B), R88.1
unnamed: Q8.1 (B), R97.1
unnamed: Q9.1 (B), R98.1
unnamed: Q10.1 (B), R99.1
unnamed: Q11.1 (B), R100.1
unnamed: Q12.1 (B), R109.1
unnamed: Q13.1 (B), R110.1
unnamed: Q14.1 (B), R111.1
unnamed: Q15.1 (B), R112.1
unnamed: Q16.1 (B), R121.1
unnamed: Q17.1 (B), R122.1
unnamed: Q18.1 (B), R123.1
unnamed: Q19.1 (B), R124.1

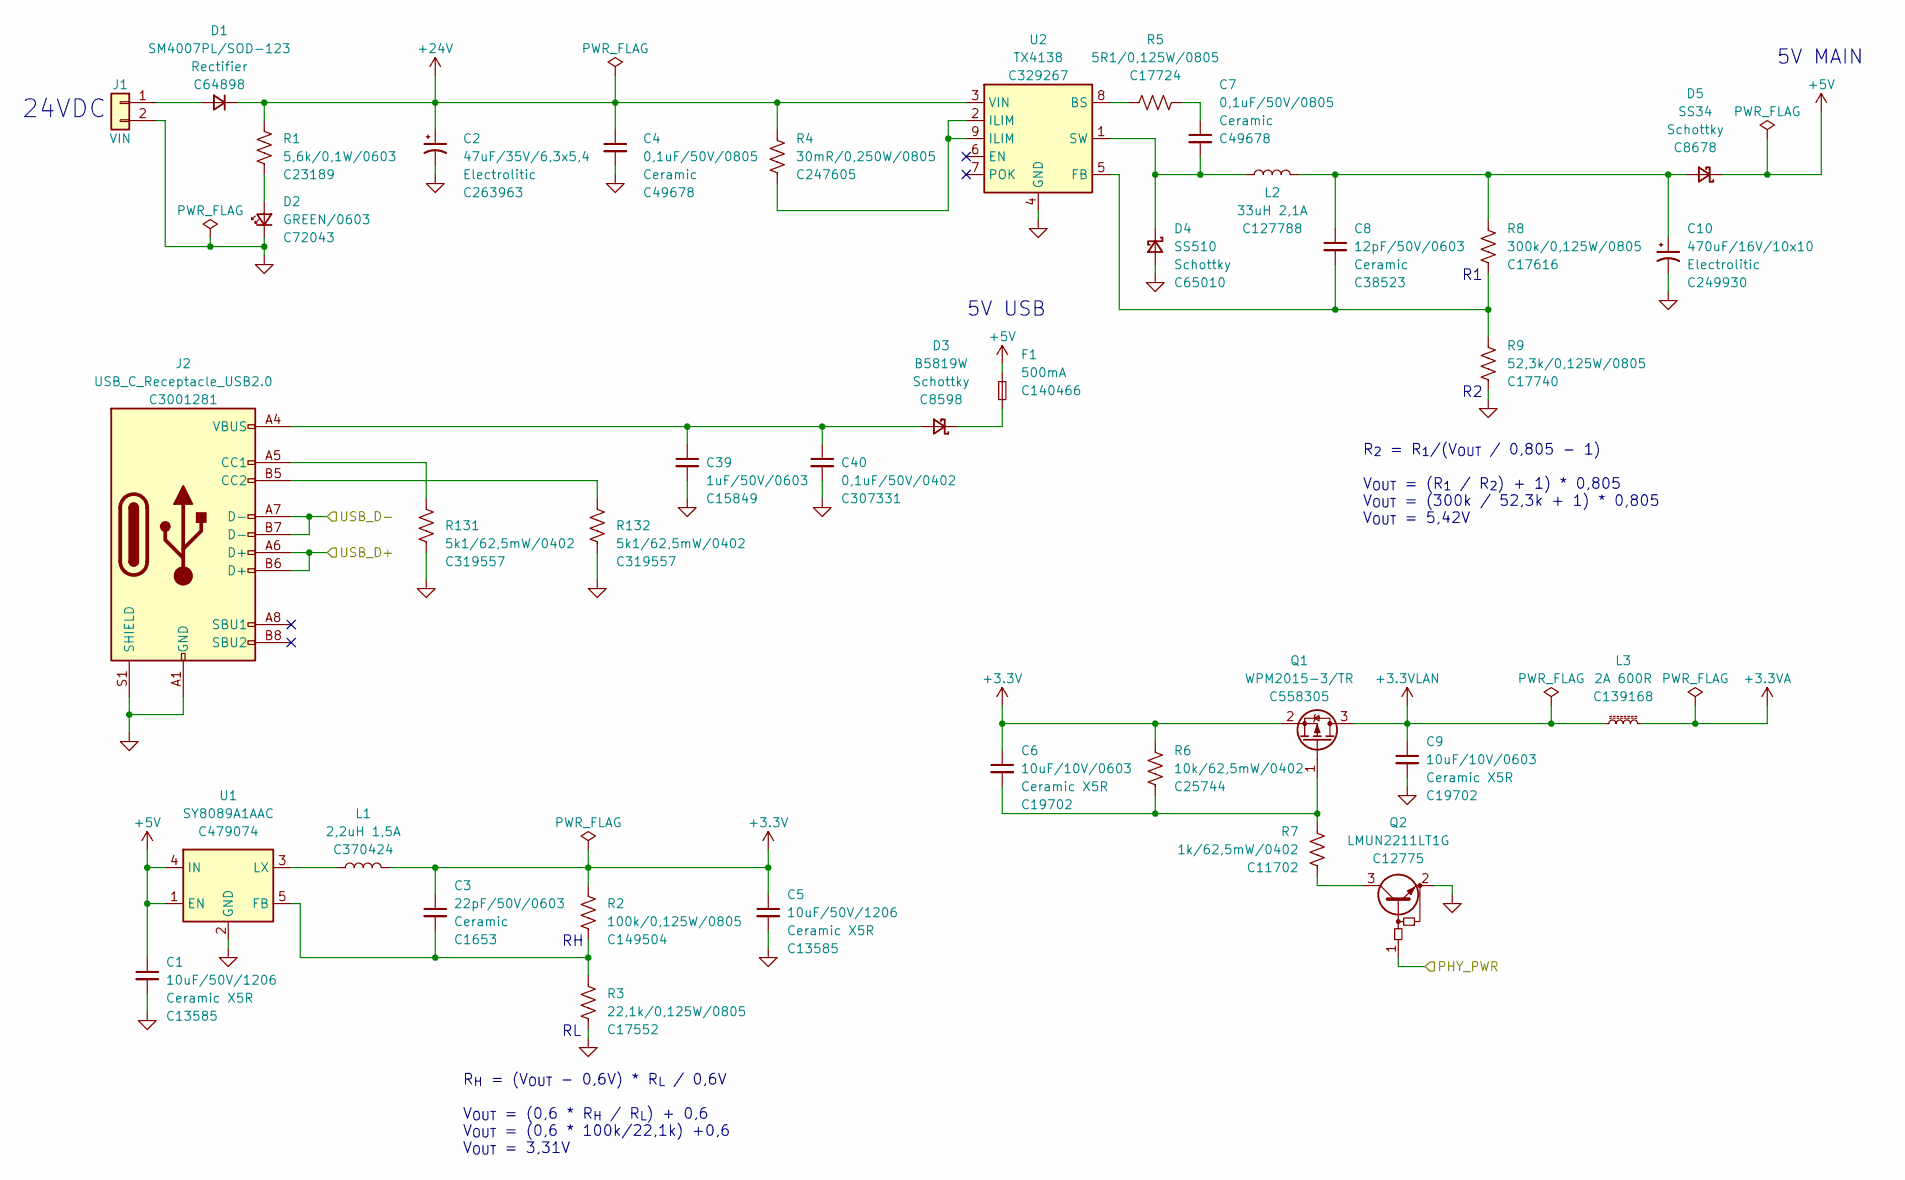
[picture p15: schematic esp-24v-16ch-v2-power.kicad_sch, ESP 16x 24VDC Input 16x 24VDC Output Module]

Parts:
C1, C5: 10uF/50V/1206; C_1206_3216Metric; Mfr PN CL31A106KBHNNNE; JLCPCB BOM 1
C2: 47uF/35V/6,3x5,4; CP_Elec_6.3x5.4; Mfr PN CK1V470MCRE54; JLCPCB BOM 1
C3: 22pF/50V/0603; C_0603_1608Metric; Mfr PN CL10C220JB8NNNC; JLCPCB BOM 1
C4, C7: 0,1uF/50V/0805; C_0805_2012Metric; Mfr PN CC0805KRX7R9BB104; LCSC Part # C49678
C6, C9: 10uF/10V/0603; C_0603_1608Metric; Mfr PN CL10A106KP8NNNC; JLCPCB BOM 1
C8: 12pF/50V/0603; C_0603_1608Metric; Mfr PN CL10C120JB8NNNC; JLCPCB BOM 1
C10: 470uF/16V/10x10; CP_Elec_10x10; Mfr PN VZH471M1CTR-1010; JLCPCB BOM 1
C39: 1uF/50V/0603; C_0603_1608Metric; Mfr PN CL10A105KB8NNNC; JLCPCB BOM 1
C40: 0,1uF/50V/0402; C_0402_1005Metric; Mfr PN CL05B104KB54PNC; JLCPCB BOM 1
D1: SM4007PL/SOD-123; D_SOD-123; Mfr PN SM4007PL; LCSC Part # C64898
D2: GREEN/0603; LED_0603_1608Metric; Mfr PN 19-217/GHC-YR1S2/3T; LCSC Part # C72043
D3: B5819W; D_SOD-123; Mfr PN B5819W; JLCPCB BOM 1
D4: SS510; D_SMA; Mfr PN SS510; JLCPCB BOM 1
D5: SS34; D_SMA; Mfr PN SS34; JLCPCB BOM 1
F1: 500mA; Fuse_1206_3216Metric; Mfr PN 12F.05000063AG12S1B02; JLCPCB BOM 1
J1: VIN; TerminalBlock_Phoenix_MKDS-3-2-5.08_1x02_P5.08mm_Horizontal; Mfr PN 1x LM 5.08/02/90 3.5SN OR BX; JLCPCB BOM 0
J2: USB_C_Receptacle_USB2.0; USB_C_Receptacle_JAE_DX07S024WJ1R350; Mfr PN GT-USB-7028D; JLCPCB BOM 1
L1: 2,2uH 1,5A; L_3x3mm_h1.5mm; Mfr PN SPH3015H2R2MT; JLCPCB BOM 1
L2: 33uH 2,1A; L_12x12mm_h6mm; Mfr PN SWRH1205B-330MT; JLCPCB BOM 1
L3: 2A 600R; L_0805_2012Metric; Mfr PN CBM201209U601T; JLCPCB BOM 1
Q1: WPM2015-3/TR; SOT-23; Mfr PN WPM2015-3/TR; JLCPCB BOM 1
Q2: LMUN2211LT1G; SOT-23; Mfr PN LMUN2211LT1G; LCSC Part # C12775
R1: 5,6k/0,1W/0603; R_0603_1608Metric; Mfr PN 0603WAF5601T5E; LCSC Part # C23189
R2: 100k/0,125W/0805; R_0805_2012Metric; Mfr PN 0805W8F1003T5E; JLCPCB BOM 1
R3: 22,1k/0,125W/0805; R_0805_2012Metric; Mfr PN 0805W8F2212T5E; JLCPCB BOM 1
R4: 30mR/0,250W/0805; R_0805_2012Metric; Mfr PN 0805W4F300MT5E; LCSC Part # C247605
R5: 5R1/0,125W/0805; R_0805_2012Metric; Mfr PN 0805W8F510KT5E; LCSC Part # C17724
R6: 10k/62,5mW/0402; R_0402_1005Metric; Mfr PN 0402WGF1002TCE; LCSC Part # C25744
R7: 1k/62,5mW/0402; R_0402_1005Metric; Mfr PN 0402WGF1001TCE; LCSC Part # C11702
R8: 300k/0,125W/0805; R_0805_2012Metric; Mfr PN 0805W8F3003T5E; JLCPCB BOM 1
R9: 52,3k/0,125W/0805; R_0805_2012Metric; Mfr PN 0805W8F5232T5E; JLCPCB BOM 1
R131, R132: 5k1/62,5mW/0402; R_0402_1005Metric; Mfr PN AR02DTD5101; JLCPCB BOM 1
U1: SY8089A1AAC; TSOT-23-5; Mfr PN SY8089A1AAC; JLCPCB BOM 1
U2: TX4138; SOIC-8-1EP_3.9x4.9mm_P1.27mm_EP2.41x3.81mm_ThermalVias; Mfr PN TX4138; JLCPCB BOM 1

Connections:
+3.3V: C3.1, C5.1, C6.1, L1.2, Q1.2 (S), R2.1, R6.1; also elsewhere on the board
+3.3VA: L3.2; also elsewhere on the board
+3.3VLAN: C9.1, L3.1, Q1.3 (D); also elsewhere on the board
+5V: C1.1, D5.1 (K), F1.2, U1.1 (EN), U1.4 (IN)
+24V: C2.1, C4.1, D1.1 (K), R1.1, R4.1, U2.3 (VIN); also elsewhere on the board
/MCU/PHY_PWR: Q2.1 (B); also elsewhere on the board
/MCU/USB_D+: J2.A6 (D+), J2.B6 (D+); also elsewhere on the board
/MCU/USB_D-: J2.A7 (D-), J2.B7 (D-); also elsewhere on the board
GND: C1.2, C2.2, C4.2, C5.2, C9.2, C10.2, C39.2, C40.2, D2.1 (K), D4.2 (A), J1.2, J2.A1 (GND), J2.A12 (GND), J2.B1 (GND), J2.B12 (GND), J2.S1 (SHIELD), Q2.2 (E), R3.2, R9.2, R131.2, R132.2, U1.2 (GND), U2.4 (GND); also elsewhere on the board
unnamed: C7.1, R5.1
unnamed: D1.2 (A), J1.1
unnamed: D2.2 (A), R1.2
unnamed: C39.1, C40.1, D3.2 (A), J2.A4 (VBUS), J2.A9 (VBUS), J2.B4 (VBUS), J2.B9 (VBUS)
unnamed: D3.1 (K), F1.1
unnamed: C7.2, D4.1 (K), L2.1, U2.1 (SW)
unnamed: C8.1, C10.1, D5.2 (A), L2.2, R8.1
unnamed: J2.A5 (CC1), R131.1
unnamed: J2.B5 (CC2), R132.1
unnamed: C6.2, Q1.1 (G), R6.2, R7.2
unnamed: Q2.3 (C), R7.1
unnamed: R4.2, U2.2 (ILIM), U2.9 (ILIM)
unnamed: C3.2, R2.2, R3.1, U1.5 (FB)
unnamed: L1.1, U1.3 (LX)
unnamed: R5.2, U2.8 (BS)
unnamed: C8.2, R8.2, R9.1, U2.5 (FB)

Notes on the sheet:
5V MAIN
5V USB
R_{H} = (V_{OUT} - 0,6V) * R_{L} / 0,6V V_{OUT} = (0,6 * R_{H} / R_{L}) + 0,6 V_{OUT} = (0,6 * 100k/22,1k) +0,6 V_{OUT} = 3,31V
R_{2} = R_{1}/(V_{OUT} / 0,805 - 1) V_{OUT} = (R_{1} / R_{2}) + 1) * 0,805 V_{OUT} = (300k / 52,3k + 1) * 0,805 V_{OUT} = 5,42V
24VDC


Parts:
C23, C24, C25, C26, C27, C28, C29, C30, C31, C32, C33, C34, C35, C36, C37, C38: 33nF/50V/0805; C_0805_2012Metric; Mfr PN 0805B333K500NT; LCSC Part # C1739
D7, D8, D9, D10, D15, D16, D17, D18, D23, D24, D25, D26, D31, D32, D33, D34: GREEN/0603; LED_0603_1608Metric; Mfr PN 19-217/GHC-YR1S2/3T; LCSC Part # C72043
D11, D12, D13, D14, D19, D20, D21, D22, D27, D28, D29, D30, D35, D36, D37, D38: 9V1/500mW; D_MiniMELF; Mfr PN ZMM9V1-M; JLCPCB BOM 1
R33, R34, R35, R36, R45, R46, R47, R48, R57, R58, R59, R60, R69, R70, R71, R72: 5,6k/0,1W/0603; R_0603_1608Metric; Mfr PN 0603WAF5601T5E; LCSC Part # C23189
R37, R38, R39, R40, R49, R50, R51, R52, R61, R62, R63, R64, R73, R74, R75, R76: 1k8/0,125W/0805; R_0805_2012Metric; Mfr PN 0805W8F1801T5E; LCSC Part # C17398
R41, R42, R43, R44, R53, R54, R55, R56, R65, R66, R67, R68, R77, R78, R79, R80: 2k2/62,5mW/0402; R_0402_1005Metric; Mfr PN 0402WGF2201TCE; LCSC Part # C25879
U8, U9, U10, U11: OR-3H4-4; SOP-16_4.4x10.4mm_P1.27mm; Mfr PN OR-3H4-4GB-TA1-GK; JLCPCB BOM 1

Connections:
+3.3V: R41.1, R42.1, R43.1, R44.1, R53.1, R54.1, R55.1, R56.1, R65.1, R66.1, R67.1, R68.1, R77.1, R78.1, R79.1, R80.1; also elsewhere on the board
/GPIO Expanders/IN1: R41.2, U8.16; also elsewhere on the board
/GPIO Expanders/IN2: R42.2, U8.14; also elsewhere on the board
/GPIO Expanders/IN3: R43.2, U8.12; also elsewhere on the board
/GPIO Expanders/IN4: R44.2, U8.10; also elsewhere on the board
/GPIO Expanders/IN5: R53.2, U9.16; also elsewhere on the board
/GPIO Expanders/IN6: R54.2, U9.14; also elsewhere on the board
/GPIO Expanders/IN7: R55.2, U9.12; also elsewhere on the board
/GPIO Expanders/IN8: R56.2, U9.10; also elsewhere on the board
/GPIO Expanders/IN9: R65.2, U10.16; also elsewhere on the board
/GPIO Expanders/IN10: R66.2, U10.14; also elsewhere on the board
/GPIO Expanders/IN11: R67.2, U10.12; also elsewhere on the board
/GPIO Expanders/IN12: R68.2, U10.10; also elsewhere on the board
/GPIO Expanders/IN13: R77.2, U11.16; also elsewhere on the board
/GPIO Expanders/IN14: R78.2, U11.14; also elsewhere on the board
/GPIO Expanders/IN15: R79.2, U11.12; also elsewhere on the board
/GPIO Expanders/IN16: R80.2, U11.10; also elsewhere on the board
/Inputs 1-16/J4-IN1: R33.1, R37.2; also elsewhere on the board
/Inputs 1-16/J4-IN2: R34.1, R38.2; also elsewhere on the board
/Inputs 1-16/J4-IN3: R35.1, R39.2; also elsewhere on the board
/Inputs 1-16/J4-IN4: R36.1, R40.2; also elsewhere on the board
/Inputs 1-16/J4-IN5: R45.1, R49.2; also elsewhere on the board
/Inputs 1-16/J4-IN6: R46.1, R50.2; also elsewhere on the board
/Inputs 1-16/J4-IN7: R47.1, R51.2; also elsewhere on the board
/Inputs 1-16/J4-IN8: R48.1, R52.2; also elsewhere on the board
/Inputs 1-16/J5-IN9: R57.1, R61.2; also elsewhere on the board
/Inputs 1-16/J5-IN10: R58.1, R62.2; also elsewhere on the board
/Inputs 1-16/J5-IN11: R59.1, R63.2; also elsewhere on the board
/Inputs 1-16/J5-IN12: R60.1, R64.2; also elsewhere on the board
/Inputs 1-16/J5-IN13: R69.1, R73.2; also elsewhere on the board
/Inputs 1-16/J5-IN14: R70.1, R74.2; also elsewhere on the board
/Inputs 1-16/J5-IN15: R71.1, R75.2; also elsewhere on the board
/Inputs 1-16/J5-IN16: R72.1, R76.2; also elsewhere on the board
GND: C23.2, C24.2, C25.2, C26.2, C27.2, C28.2, C29.2, C30.2, C31.2, C32.2, C33.2, C34.2, C35.2, C36.2, C37.2, C38.2, D7.1 (K), D8.1 (K), D9.1 (K), D10.1 (K), D15.1 (K), D16.1 (K), D17.1 (K), D18.1 (K), D23.1 (K), D24.1 (K), D25.1 (K), D26.1 (K), D31.1 (K), D32.1 (K), D33.1 (K), D34.1 (K), U8.2, U8.4, U8.6, U8.8, U8.9, U8.11, U8.13, U8.15, U9.2, U9.4, U9.6, U9.8, U9.9, U9.11, U9.13, U9.15, U10.2, U10.4, U10.6, U10.8, U10.9, U10.11, U10.13, U10.15, U11.2, U11.4, U11.6, U11.8, U11.9, U11.11, U11.13, U11.15; also elsewhere on the board
unnamed: D7.2 (A), R33.2
unnamed: D8.2 (A), R34.2
unnamed: D9.2 (A), R35.2
unnamed: D10.2 (A), R36.2
unnamed: D11.2 (A), U8.1
unnamed: C23.1, D11.1 (K), R37.1
unnamed: D12.2 (A), U8.3
unnamed: C24.1, D12.1 (K), R38.1
unnamed: D13.2 (A), U8.5
unnamed: C25.1, D13.1 (K), R39.1
unnamed: D14.2 (A), U8.7
unnamed: C26.1, D14.1 (K), R40.1
unnamed: D15.2 (A), R45.2
unnamed: D16.2 (A), R46.2
unnamed: D17.2 (A), R47.2
unnamed: D18.2 (A), R48.2
unnamed: D19.2 (A), U9.1
unnamed: C27.1, D19.1 (K), R49.1
unnamed: D20.2 (A), U9.3
unnamed: C28.1, D20.1 (K), R50.1
unnamed: D21.2 (A), U9.5
unnamed: C29.1, D21.1 (K), R51.1
unnamed: D22.2 (A), U9.7
unnamed: C30.1, D22.1 (K), R52.1
unnamed: D23.2 (A), R57.2
unnamed: D24.2 (A), R58.2
unnamed: D25.2 (A), R59.2
unnamed: D26.2 (A), R60.2
unnamed: D27.2 (A), U10.1
unnamed: C31.1, D27.1 (K), R61.1
unnamed: D28.2 (A), U10.3
unnamed: C32.1, D28.1 (K), R62.1
unnamed: D29.2 (A), U10.5
unnamed: C33.1, D29.1 (K), R63.1
unnamed: D30.2 (A), U10.7
unnamed: C34.1, D30.1 (K), R64.1
unnamed: D31.2 (A), R69.2
unnamed: D32.2 (A), R70.2
unnamed: D33.2 (A), R71.2
unnamed: D34.2 (A), R72.2
unnamed: D35.2 (A), U11.1
unnamed: C35.1, D35.1 (K), R73.1
unnamed: D36.2 (A), U11.3
unnamed: C36.1, D36.1 (K), R74.1
unnamed: D37.2 (A), U11.5
unnamed: C37.1, D37.1 (K), R75.1
unnamed: D38.2 (A), U11.7
unnamed: C38.1, D38.1 (K), R76.1

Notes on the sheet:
ENTRADA OPTO Corrente na entrada 24V - 9,1V -1,2V = 13,7V 13,7V / 1800R = 7,62mA Potência dissipada no resistor série 1800 x SQ(0,00762) = 0,1045 104,5mW - usar resistor 125mW
SAÍDA OPTO CTR opto com i=8mA e Vce = 0,4V ~= 150% Corrente na saída do opto pode chegar a 12mA Corrente máxima prevista na saída do opto 3,3V - 0,4V = 2,9V 2,9V / 2200R = 1,32mA


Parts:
R31, R32: 1k/62,5mW/0402; R_0402_1005Metric; Mfr PN 0402WGF1001TCE; LCSC Part # C11702
U6, U7: MCP23017_SS; SSOP-28_5.3x10.2mm_P0.65mm; Mfr PN MCP23017T-E/SS; JLCPCB BOM 1

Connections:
+3.3V: R31.1, R32.1, U6.9 (VDD), U7.9 (VDD), U7.16 (A1); also elsewhere on the board
/GPIO Expanders/IN1: U6.21 (GPA0); also elsewhere on the board
/GPIO Expanders/IN2: U6.22 (GPA1); also elsewhere on the board
/GPIO Expanders/IN3: U6.23 (GPA2); also elsewhere on the board
/GPIO Expanders/IN4: U6.24 (GPA3); also elsewhere on the board
/GPIO Expanders/IN5: U6.25 (GPA4); also elsewhere on the board
/GPIO Expanders/IN6: U6.26 (GPA5); also elsewhere on the board
/GPIO Expanders/IN7: U6.27 (GPA6); also elsewhere on the board
/GPIO Expanders/IN8: U6.28 (GPA7); also elsewhere on the board
/GPIO Expanders/IN9: U6.1 (GPB0); also elsewhere on the board
/GPIO Expanders/IN10: U6.2 (GPB1); also elsewhere on the board
/GPIO Expanders/IN11: U6.3 (GPB2); also elsewhere on the board
/GPIO Expanders/IN12: U6.4 (GPB3); also elsewhere on the board
/GPIO Expanders/IN13: U6.5 (GPB4); also elsewhere on the board
/GPIO Expanders/IN14: U6.6 (GPB5); also elsewhere on the board
/GPIO Expanders/IN15: U6.7 (GPB6); also elsewhere on the board
/GPIO Expanders/IN16: U6.8 (GPB7); also elsewhere on the board
/GPIO Expanders/MCP1-INTA: U6.20 (INTA); also elsewhere on the board
/GPIO Expanders/MCP1-INTB: U6.19 (INTB); also elsewhere on the board
/GPIO Expanders/OUT1: U7.21 (GPA0); also elsewhere on the board
/GPIO Expanders/OUT2: U7.22 (GPA1); also elsewhere on the board
/GPIO Expanders/OUT3: U7.23 (GPA2); also elsewhere on the board
/GPIO Expanders/OUT4: U7.24 (GPA3); also elsewhere on the board
/GPIO Expanders/OUT5: U7.25 (GPA4); also elsewhere on the board
/GPIO Expanders/OUT6: U7.26 (GPA5); also elsewhere on the board
/GPIO Expanders/OUT7: U7.27 (GPA6); also elsewhere on the board
/GPIO Expanders/OUT8: U7.28 (GPA7); also elsewhere on the board
/GPIO Expanders/OUT9: U7.1 (GPB0); also elsewhere on the board
/GPIO Expanders/OUT10: U7.2 (GPB1); also elsewhere on the board
/GPIO Expanders/OUT11: U7.3 (GPB2); also elsewhere on the board
/GPIO Expanders/OUT12: U7.4 (GPB3); also elsewhere on the board
/GPIO Expanders/OUT13: U7.5 (GPB4); also elsewhere on the board
/GPIO Expanders/OUT14: U7.6 (GPB5); also elsewhere on the board
/GPIO Expanders/OUT15: U7.7 (GPB6); also elsewhere on the board
/GPIO Expanders/OUT16: U7.8 (GPB7); also elsewhere on the board
/MCU/I2C_SCL: U6.12 (SCK), U7.12 (SCK); also elsewhere on the board
/MCU/I2C_SDA: U6.13 (SDA), U7.13 (SDA); also elsewhere on the board
GND: U6.10 (VSS), U6.15 (A0), U6.16 (A1), U6.17 (A2), U7.10 (VSS), U7.15 (A0), U7.17 (A2); also elsewhere on the board
unnamed: R31.2, U6.18 (~RESET)
unnamed: R32.2, U7.18 (~RESET)

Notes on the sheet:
OUTPUTS ADDRESS 0x22
INPUTS ADDRESS 0x20


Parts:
C14: 1nF/2kV/1206; C_1206_3216Metric; Mfr PN VJ1206Y102MXFAT4X; JLCPCB BOM 1
C15, C18, C19, C20: 0,1uF/50V/0402; C_0402_1005Metric; Mfr PN CL05B104KB54PNC; JLCPCB BOM 1
C16, C17: 10uF/10V/0603; C_0603_1608Metric; Mfr PN CL10A106KP8NNNC; JLCPCB BOM 1
C21: 1uF/25V/0402; C_0402_1005Metric; Mfr PN CL05A105KA5NQNC; JLCPCB BOM 1
C22: 470pF/50V/0402; C_0402_1005Metric; Mfr PN 0402B471K500NT; JLCPCB BOM 1
D6: ESDS314DBV; SOT-23-5; Mfr PN ESDS314DBVR; JLCPCB BOM 1
J7: ETHERNET; RJ45_HanRun_HR911105A; Mfr PN HR911105A; JLCPCB BOM 1
R15, R18, R19, R20, R21, R22, R23, R25: 2k2/62,5mW/0402; R_0402_1005Metric; Mfr PN 0402WGF2201TCE; LCSC Part # C25879
R16, R17: 330R/62,5mW/0402; R_0402_1005Metric; Mfr PN 0402WGF3300TCE; LCSC Part # C25104
R24: 10k/62,5mW/0402; R_0402_1005Metric; Mfr PN 0402WGF1002TCE; LCSC Part # C25744
R26: 12,1k/62,5mW/0402; R_0402_1005Metric; Mfr PN 0402WGF1212TCE; JLCPCB BOM 1
R27, R28, R29, R30: 49,9R/62,5mW/0402; R_0402_1005Metric; Mfr PN 0402WGF499JTCE; LCSC Part # C25120
U5: LAN8710A; QFN-32-1EP_5x5mm_P0.5mm_EP3.3x3.3mm_ThermalVias; Mfr PN LAN8710A-EZC-TR; JLCPCB BOM 1

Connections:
+3.3VA: C15.1, C19.1, C20.1, J7.4, J7.5, R16.1, R27.2, R28.2, R29.2, R30.2, U5.1 (VDD2A), U5.27 (VDD1A); also elsewhere on the board
+3.3VLAN: C16.1, C18.1, R15.1, R18.1, R19.1, R22.1, R24.1, R25.1, U5.12 (VDDIO); also elsewhere on the board
/LAN/EMAC_CLK: U5.5 (XTAL1/CLKIN); also elsewhere on the board
/LAN/EMAC_MDC: U5.17 (MDC); also elsewhere on the board
/LAN/EMAC_MDIO: R22.2, U5.16 (MDIO); also elsewhere on the board
/LAN/EMAC_RX: R25.2, U5.15 (COL/CRS_DV/~MODE2); also elsewhere on the board
/LAN/EMAC_RXD0: R19.2, U5.11 (RXD0/~MODE0); also elsewhere on the board
/LAN/EMAC_RXD1: R18.2, U5.10 (RXD1/~MODE1); also elsewhere on the board
/LAN/EMAC_TXD0: U5.22 (TXD0); also elsewhere on the board
/LAN/EMAC_TXD1: U5.23 (TXD1); also elsewhere on the board
/LAN/EMAC_TXEN: U5.21 (TXEN); also elsewhere on the board
/LAN/LED_G_K: J7.10, U5.2 (LED2/~INTSEL)
/LAN/LED_Y_A: R17.1, U5.3 (LED1/~REGOFF)
/LAN/RD+: D6.5 (I/04), J7.3 (RD+), R29.1, U5.31 (RXP)
/LAN/RD-: D6.1 (I/01), J7.6 (RD-), R30.1, U5.30 (RXN)
/LAN/TD+: D6.4 (I/03), J7.1 (TD+), R27.1, U5.29 (TXP)
/LAN/TD-: D6.3 (I/02), J7.2 (TD-), R28.1, U5.28 (TXN)
GND: C14.2, C15.2, C16.2, C17.2, C18.2, C19.2, C20.2, C21.2, C22.2, D6.2 (GND), J7.8, J7.11, R20.2, R21.2, R23.2, R26.2, U5.24 (TXD2), U5.25 (TXD3), U5.33 (VSS); also elsewhere on the board
unnamed: C14.1, J7.SH
unnamed: J7.9, R16.2
unnamed: J7.12, R17.2
unnamed: R26.1, U5.32 (RBIAS)
unnamed: R21.1, U5.7 (RXCLK/~PHYAD1)
unnamed: R15.2, U5.9 (RXD2/~RMIISEL)
unnamed: R20.1, U5.8 (RXD3/~PHYAD2)
unnamed: R23.1, U5.13 (RXER/RXD4/~PHYAD0)
unnamed: C21.1, C22.1, U5.6 (VDDCR)
unnamed: C17.1, R24.2, U5.19 (~RST)

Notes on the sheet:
OPÇÕES RJ45 HANRUN HR911105A JLCPCB C12074 HORIZONTAL MAGNÉTICO HANRUN HY951180A JLCPCB C34677 VERTICAL MAGNÉTICO

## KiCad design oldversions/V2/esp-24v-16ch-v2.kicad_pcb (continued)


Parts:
C11: 10uF/10V/0603; C_0603_1608Metric; Mfr PN CL10A106KP8NNNC; LCSC Part # C19702
C12: 0,1uF/50V/0805; C_0805_2012Metric; Mfr PN CC0805KRX7R9BB104; LCSC Part # C49678
C13: 1uF/50V/0603; C_0603_1608Metric; Mfr PN CL10A105KB8NNNC; JLCPCB BOM 1
Q3: UMH3N; SOT-363_SC-70-6; Mfr PN UMH3N; JLCPCB BOM 1
R10, R11, R12: 10k/62,5mW/0402; R_0402_1005Metric; Mfr PN 0402WGF1002TCE; LCSC Part # C25744
R13, R14, R129, R130: 2k2/62,5mW/0402; R_0402_1005Metric; Mfr PN 0402WGF2201TCE; LCSC Part # C25879
SW1: RESET; SW_SPST_TL3342; Mfr PN TS-1187A-B-A-B; JLCPCB BOM 1
U3: CH340C; SOIC-16_3.9x9.9mm_P1.27mm; Mfr PN CH340C; JLCPCB BOM 1
U4: ESP32-WROOM-32UE-N16; ESP32-WROOM-32U; Mfr PN ESP32-WROOM-32UE-N16; JLCPCB BOM 1

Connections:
+3.3V: C11.1, C12.1, R10.1, R11.1, R13.1, R14.1, R129.1, R130.1, U3.4 (V3), U3.16 (VCC), U4.2 (VDD); also elsewhere on the board
/GPIO Expanders/MCP1-INTA: R129.2, U4.16 (IO13); also elsewhere on the board
/GPIO Expanders/MCP1-INTB: R130.2, U4.13 (IO14); also elsewhere on the board
/LAN/EMAC_CLK: U4.28 (IO17); also elsewhere on the board
/LAN/EMAC_MDC: U4.37 (IO23); also elsewhere on the board
/LAN/EMAC_MDIO: U4.30 (IO18); also elsewhere on the board
/LAN/EMAC_RX: U4.12 (IO27); also elsewhere on the board
/LAN/EMAC_RXD0: U4.10 (IO25); also elsewhere on the board
/LAN/EMAC_RXD1: U4.11 (IO26); also elsewhere on the board
/LAN/EMAC_TXD0: U4.31 (IO19); also elsewhere on the board
/LAN/EMAC_TXD1: U4.36 (IO22); also elsewhere on the board
/LAN/EMAC_TXEN: U4.33 (IO21); also elsewhere on the board
/MCU/I2C_SCL: R13.2, U4.8 (IO32); also elsewhere on the board
/MCU/I2C_SDA: R14.2, U4.9 (IO33); also elsewhere on the board
/MCU/PHY_PWR: R12.1, U4.14 (IO12); also elsewhere on the board
/MCU/USB_D+: U3.5 (UD+); also elsewhere on the board
/MCU/USB_D-: U3.6 (UD-); also elsewhere on the board
GND: C11.2, C12.2, C13.2, R12.2, SW1.1, U3.1 (GND), U4.1 (GND), U4.15 (GND), U4.38 (GND), U4.39 (GND); also elsewhere on the board
unnamed: Q3.2 (B1), Q3.4 (E2), U3.13 (~DTR)
unnamed: C13.1, Q3.6 (C1), R10.2, SW1.2, U4.3 (EN)
unnamed: Q3.1 (E1), Q3.5 (B2), U3.14 (~RTS)
unnamed: Q3.3 (C2), R11.2, U4.25 (IO0)
unnamed: U3.3 (RXD), U4.35 (TXD0/IO1)
unnamed: U3.2 (TXD), U4.34 (RXD0/IO3)

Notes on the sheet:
TASMOTA GENERAL CONFIGURATIONS The configs below must be applied via terminal/console and adjusted according to the desired hostname, device name, network addresses and behavior of switches. backlog switchmode1 5; switchmode2 5; switchmode3 5; switchmode4 5; switchmode5 5; switchmode6 5; switchmode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
ESP32 PIN ASSIGNMENT 25 - GPIO0 - AUTO FLASH MODE 35 - GPIO1 - SERIAL TX 34 - GPIO3 - SERIAL RX 14 - GPIO12 - PHY POWER 16 - GPIO13 - MCP23017 INTA 13 - GPIO14 - MCP23017 INTB 28 - GPIO17 - EMAC CLK 30 - GPIO18 - EMAC MDIO 31 - GPIO19 - EMAC TXD0 33 - GPIO21 - EMAC TXEN 36 - GPIO22 - EMAC TXD1 37 -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
TEMPLATE FOR GPIO ASSIGNMENT {"NAME":"ESP-24V-16CH-V2","GPIO":[0,3200,0,3232,0,0,0,0,5536,10240,10241,0,0, 0,5600,0,0,0,0,5568,0,0,0,0,0,0,0,0,608,640,0,0,0,0,0,0],"FLAG":0,"BASE":1} See https://tasmota.github.io/docs/Templates/
TEMPLATE FOR MCP23017 I/O ASSIGNMENT {"NAME":"MCP23017 expander","BASE":0,"GPIO":[160,161,162,163,164,165,166,167,168,169,170, 171,172,173,174,175,224,225,226,227,228,229,230,231,232,233,234,235,236,237,238,239]} Save as mcp23x.dat and load into tasmota's filesystem. See https://tasmota.github.io/d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


Board: 2 copper layers, 138.0 x 67.8 mm, 268 parts (0 on the bottom side), 206 nets.

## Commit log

2026-06-01 V6 is up
    [bom.csv, designators.csv, esp-24v-16ch-v5-i2c.kicad_sch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]
2026-06-02 Layout improvements
    [esp-24v-16ch-v6.kicad_pcb]
2026-06-02 Update V6 PCB routing, fabrication and production files
    Modify V6 board assets: updated esp-24v-16ch board image and kicad_pcb with numerous trace/via relocations, segment coordinate changes, updated UUIDs, and net/routing adjustments (LAN/EMAC, USB/5V, +3V3, +5V). Also updated fabrication-toolkit options, production ZIP, and netlist.ipc to reflect the revised layout. These changes appear to be routing cleanup and power/IO rework for the V6 revision.
    [esp-24v-16ch-v6.kicad_pcb]
2026-06-02 Fix output current rating in README
    Updated output current rating from 600mA to 500mA in the README.
2026-06-02 Update README with new image and version history
    Updated image link and added detailed version history for ESP-24V-16CH V6.0.
2026-06-02 Silkscreen adjustments
    [esp-24v-16ch-v6.kicad_pcb, positions.csv]
2026-06-02 Minor schematic adjustment
    [esp-24v-16ch-v6-power.kicad_sch, esp-24v-16ch-v6.kicad_pcb]
2026-06-03 addressing the PHY power rails
    [esp-24v-16ch-v6-lan.kicad_sch, esp-24v-16ch-v6-power.kicad_sch]
2026-06-03 Revising power rails
    [bom.csv, designators.csv, esp-24v-16ch-v6-i2c.kicad_sch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]
2026-06-03 Update inductor footprints
    [esp-24v-16ch-v6-power.kicad_sch]
2026-06-06 ESP32 repositioned for shorter PHY traces.
    [esp-24v-16ch-v6-i2c.kicad_sch, esp-24v-16ch-v6-lan.kicad_sch, esp-24v-16ch-v6.kicad_pcb]
2026-06-07 Included test points
    [bom.csv, designators.csv, esp-24v-16ch-v6-i2c.kicad_sch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]
2026-06-07 Removed test points that didn't fit the PCB
    [esp-24v-16ch-v6-lan.kicad_sch, esp-24v-16ch-v6-power.kicad_sch, esp-24v-16ch-v6.kicad_pcb]
2026-06-07 Update version history for ESP-24V-16CH V6.0
    Updated version history for ESP-24V-16CH to reflect changes in V6.0, including repositioning of ESP32, addition of test points, and various improvements for better performance and layout.
2026-06-07 Correcting JLCPBC part number for J8 ethernet connector
    [bom.csv, esp-24v-16ch-v6-lan.kicad_sch, esp-24v-16ch-v6.kicad_pcb]
2026-06-08 Included a shunt resistor on the 5V rail, for measuring current during development.
    [bom.csv, designators.csv, esp-24v-16ch-v6-i2c.kicad_sch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]
2026-06-08 Added relase date to PCB
    [esp-24v-16ch-v6.kicad_pcb]
2026-06-09 Update resistance value for pull-ups.
    [bom.csv, esp-24v-16ch-v6-lan.kicad_sch, esp-24v-16ch-v6-mcu.kicad_sch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]
2026-06-09 Added voltage monitors for both ESP32 and LAN8710A
    [bom.csv, designators.csv, esp-24v-16ch-v6-i2c.kicad_sch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]
2026-06-09 Updated version number on the silkscreen.
    [esp-24v-16ch-v6.kicad_pcb]
2026-06-12 Streamlining version numbers.
    [esp-24v-16ch-v6-i2c.kicad_sch, esp-24v-16ch-v6-inputs1-8.kicad_sch, esp-24v-16ch-v6-inputs9-16.kicad_sch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]
2026-06-13 Moved old versions to the oldversions folder
    [esp-24v-16ch-outputs.kicad_sch, esp-24v-16ch-v2-expanders.kicad_sch, esp-24v-16ch-v2-inputs-1.kicad_sch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]
2026-06-13 Renamed all files to eumesmo branding
    [eumesmo-io-24v16ch-v6-i2c.kicad_sch, eumesmo-io-24v16ch-v6-inputs1-8.kicad_sch, eumesmo-io-24v16ch-v6-inputs9-16.kicad_sch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]
2026-06-13 Adjusted PCB version number
    [eumesmo-io-24v16ch-v6.kicad_pcb]
2026-06-16 Adjusted keepout area under the magjack.
    [eumesmo-io-24v16ch-v6.kicad_pcb]
2026-06-17 Widened tracks at pads and vias.
    [eumesmo-io-24v16ch-v6.kicad_pcb]
2026-06-17 Release V6.2.0
    [eumesmo-io-24v16ch-v6-i2c.kicad_sch, eumesmo-io-24v16ch-v6-inputs1-8.kicad_sch, eumesmo-io-24v16ch-v6-inputs9-16.kicad_sch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]
2026-06-29 Added CPU health LED
    [bom.csv, designators.csv, eumesmo-io-24v16ch-v6-i2c.kicad_sch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]
2026-09-09 Further improved routing between ETH jack and LAN8710A.
    [eumesmo-io-24v16ch-v6.kicad_pcb, positions.csv]
2026-09-10 Further improvements to routing between ETH jack and LAN IC.
    [designators.csv, eumesmo-io-24v16ch-v6-i2c.kicad_sch, eumesmo-io-24v16ch-v6.kicad_pcb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]
2026-09-10 Replaced white leds for emerald.
    [bom.csv, eumesmo-io-24v16ch-v6-inputs1-8.kicad_sch, eumesmo-io-24v16ch-v6-inputs9-16.kicad_sch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]
2026-09-10 Remove jumpers from BOM.
    [bom.csv, eumesmo-io-24v16ch-v6-i2c.kicad_sch, eumesmo-io-24v16ch-v6-inputs1-8.kicad_sch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]
2026-09-10 Replaced board image.
2026-09-11 LEDs changed to orange
    [bom.csv, eumesmo-io-24v16ch-v6-inputs1-8.kicad_sch, eumesmo-io-24v16ch-v6-inputs9-16.kicad_sch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]
2026-09-11 LEDs replaced for orange
    [bom.csv, eumesmo-io-24v16ch-v6-inputs1-8.kicad_sch, eumesmo-io-24v16ch-v6-inputs9-16.kicad_sch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]
2026-09-21 Adjusted component rotation and offset information for JLCPCB.
    [eumesmo-io-24v16ch-v6-i2c.kicad_sch, eumesmo-io-24v16ch-v6-inputs1-8.kicad_sch, eumesmo-io-24v16ch-v6-inputs9-16.kicad_sch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]
2026-09-21 Adjusted comment regarding DIN rail modules.
    [eumesmo-io-24v16ch-v6.kicad_pcb]
2026-09-21 Updated component visible fields.
    [eumesmo-io-24v16ch-v6-i2c.kicad_sch, eumesmo-io-24v16ch-v6-inputs1-8.kicad_sch, eumesmo-io-24v16ch-v6-inputs9-16.kicad_sch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]
2026-09-21 Dev branch test
    [eumesmo-io-24v16ch-v6.kicad_pcb]
2026-09-22 Connectors moved up into the board.
    [bom.csv, designators.csv, eumesmo-io-24v16ch-v6-i2c.kicad_sch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]
2026-09-22 Generated fabrication files.
    [eumesmo-io-24v16ch-v6-i2c.kicad_sch, eumesmo-io-24v16ch-v6-inputs1-8.kicad_sch, eumesmo-io-24v16ch-v6-inputs9-16.kicad_sch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]
2026-10-19 Replaced Wago connectors for other brand, no stock.
